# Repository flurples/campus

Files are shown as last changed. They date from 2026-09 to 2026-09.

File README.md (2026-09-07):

# campus
mechanical keyboard conversion for a framework 13

IMG_3377-adjusted
build video: https://youtu.be/kGHAUogFsYY

## about
campus is designed to be a drop-in replacement housing for a framework 13 that features a hhkb layout kailh choc mechanical keyboard.

## you will need
- a framework 13 laptop
#### bottom chassis parts
- bottom chassis (cnc)
- bottom-bracket-R, L & M (3d print)
#### input cover parts
- input cover (cnc)
- plate (cnc)
- 3x knobs (cnc)
- 1x touchpad-clamp-R & L (3d print)
- 2x touchpad-clamp-top (3d print)
#### lid parts
- lid (cnc)
- bezel (3d print)
- lid-corner-cap-R & L (3d print)
#### other hardware
- 60x kailh choc switches
- choc stabilizers (2x 2u, 1x 6.25u)
- compatible keycaps (be sure to get 6.25u space, 1.75u shift, etc)
- 3x ec12 low profile encoders
- m1.6 x 3mm heat set inserts
- m2 x 4mm heat set inserts
- m2 x 2.5mm heat set inserts
- 5x m2 x 20mm flat head hex screws (to screw the chassis together)
- 3x m2 x 8mm set screws (for the knobs)
- 4x 1" OD rubber bumpers
- variety of double sided tapes
- epoxy

## build notes
bottom chassis, input cover, lid, knobs, and plate were cnc'd from aluminum. all 3d printed parts were printed in petg to avoid breaking down over the years. heat set inserts for screw holes to mount factory components are installed into the bottom-brackets, which are then epoxied to the bottom-chassis. due to jlcpcb's minimum thickness requirements, the input and lid do not use heat set inserts. instead, the aluminum is directly tapped.

#### the keyboard workaround
the usb hub was too complex and I wasn't able to get it working. because the keyboard was originally meant to connect internally through the usb hub, I ended up simply bypassing the usb hub entirely, bypassing it with a unified daughterboard s1.
in case anyone wants to attempt to diagnose why, I've uploaded the kicad files as is for reference.

## disclaimer
campus is a highly involved project and will require completely tearing down your framework laptop and transplanting all the components into an objectively worse-designed chassis than the factory framework chassis. some features will be lost, for example, the privacy switches built into the webcam module, or the little buttons that lock the expansion cards in place. I am not a professional electronics designer, so expect to perform some janky workarounds to get the laptop functioning as it should. I am not responsible for any issues you may encounter with the build, so please use the files with caution.

I do not sell any products, and I am not affiliated with any vendors who claim to sell my designs. if you choose to support these vendors, I am not responsible for any issues you may encounter with them.

## gallery






IMG_E3424

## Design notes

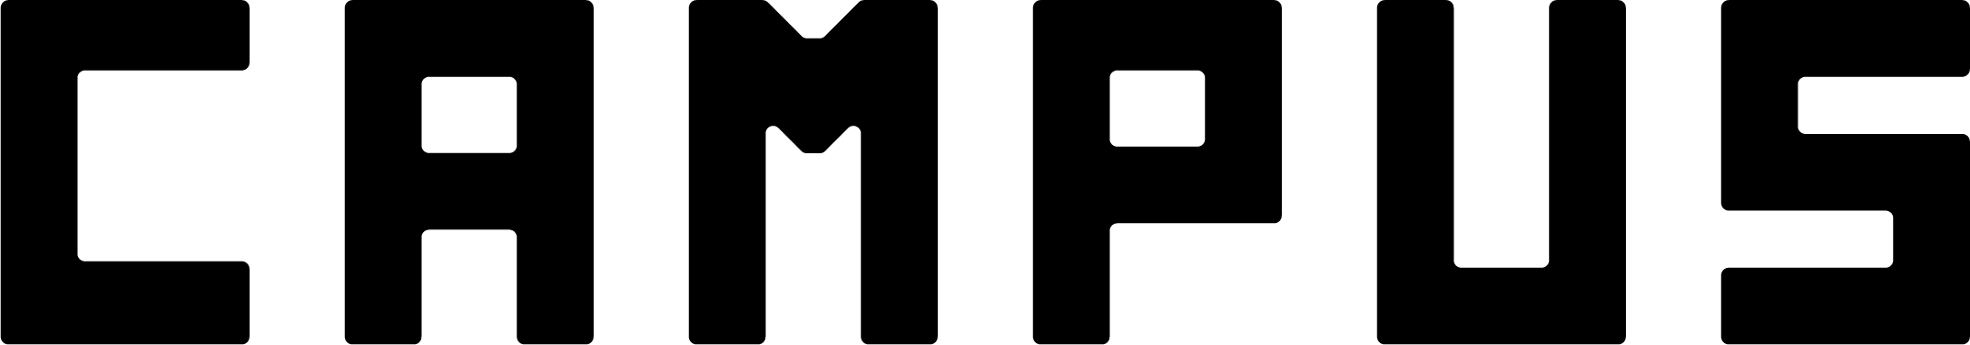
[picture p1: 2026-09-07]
graphics/campus-text.png

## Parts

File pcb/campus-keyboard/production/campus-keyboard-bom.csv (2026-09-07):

Comment | Designator | Footprint | LCSC Part Number
22pF | C1,C2 | Capacitor_SMD:C_0805_2012Metric | C1804
1uF | C3 | Capacitor_SMD:C_0805_2012Metric | C28323
0.1uF | C4,C5,C6 | Capacitor_SMD:C_0805_2012Metric | C1711
10uF | C7 | Capacitor_SMD:C_0805_2012Metric | C1713
SOD-123 | D1,D2,D3,D4,D5,D6,D7,D8,D9,D10,D11,D12,D13,D14,D15,D16,D17,D18,D19,D20,D21,D22,D23,D24,D25,D26,D27,D28,D29,D30,D31,D32,D33,D34,D35,D36,D37,D38,D39,D40,D41,D42,D43,D44,D45,D46,D47,D48,D49,D50,D51,D52,D53,D54,D55,D56,D57,D58,D59,D60 | Diode_SMD:D_SOD-123 | C2099
500mA | F1 | Fuse:Fuse_1206_3216Metric | C720075
Conn_01x04 | J1 | Connector_Molex:Molex_Pico-EZmate_78171-0004_1x04-1MP_P1.20mm_Vertical | C588524
SI2302 | Q1 | Package_TO_SOT_SMD:SOT-23 | C2891732
470 | R1,R2,R3,R4,R5,R6,R7,R8,R9,R10,R11,R12,R13,R14,R15,R16,R17,R18,R19,R20,R21,R22,R23,R24,R25,R26,R27,R28,R29,R30,R31,R32,R33,R34,R35,R36,R37,R38,R39,R40,R41,R42,R43,R44,R45,R46,R47,R48,R49,R50,R51,R52,R53,R54,R55,R56,R57,R58,R59,R60,R61,R62,R63,R64,R65,R66,R67,R68,R69,R70,R71,R72,R73,R74,R75,R76,R77,R78,R79,R80,R81 | campus-parts:R_0805_2012Metric | C17710
10k | R82,R83,R86 | campus-parts:R_0805_2012Metric | C17414
22 | R84,R85 | campus-parts:R_0805_2012Metric | C17561
SW_Push | SW1 | random-keyboard-parts:SKQG-1155865 | C5140332
ATmega32U4-MU | U1 | Package_DFN_QFN:QFN-44-1EP_7x7mm_P0.5mm_EP5.2x5.2mm | C112161
16MHz | Y1 | Crystal:Crystal_SMD_3225-4Pin_3.2x2.5mm | C13738

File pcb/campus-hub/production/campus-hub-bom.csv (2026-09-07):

Comment | Designator | Footprint | LCSC Part Number
10uF | C9 | Capacitor_SMD:C_0805_2012Metric | C1713
1uF | C13 | Capacitor_SMD:C_0805_2012Metric | C28323
22uF | C14 | Capacitor_SMD:C_0805_2012Metric | C5674
4.7uF | C18,C30 | Capacitor_SMD:C_0805_2012Metric | C1779
22pF | C23,C24,C33,C34 | Capacitor_SMD:C_0805_2012Metric | C1804
0.33uF | C5,C6 | Capacitor_SMD:C_0805_2012Metric | C73142
0.1uF | C7,C8,C10,C11,C12,C15,C16,C17,C19,C20,C21,C22,C25,C26,C27,C28,C29,C31,C32,C35,C36,C37,C38 | Capacitor_SMD:C_0805_2012Metric | C1711
1uH | L1 | Inductor_SMD:L_1008_2520Metric | C5179444
5.1k | R1 | Resistor_SMD:R_0805_2012Metric | C27834
24.9k | R2 | Resistor_SMD:R_0805_2012Metric | C17571
113k | R3 | Resistor_SMD:R_0805_2012Metric | C17424
1M | R5 | Resistor_SMD:R_0805_2012Metric | C2889485
33 | R11 | Resistor_SMD:R_0805_2012Metric | C17634
12k | R4,R12 | Resistor_SMD:R_0805_2012Metric | C17444
10k | R6,R7,R8,R9,R10,R14,R15 | Resistor_SMD:R_0805_2012Metric | C17414
TUSB1046-DCIRNQR | U1 | campus-parts:RNQ40_TEX | C2151061
USB5744/2G | U2 | campus-parts:VQFN56_2G_MCH | C633621
TPS62901RPJR | U3 | campus-parts:QFN_902RPJR_TEX | C2864847
USB2244-AEZG-06 | U4 | campus-parts:QFN36_6X6MC_MCH | C2674043
25MHz | Y1 | Crystal:Crystal_SMD_3225-4Pin_3.2x2.5mm | C9006
24MHz | Y2 | Crystal:Crystal_SMD_3225-4Pin_3.2x2.5mm | C7294566

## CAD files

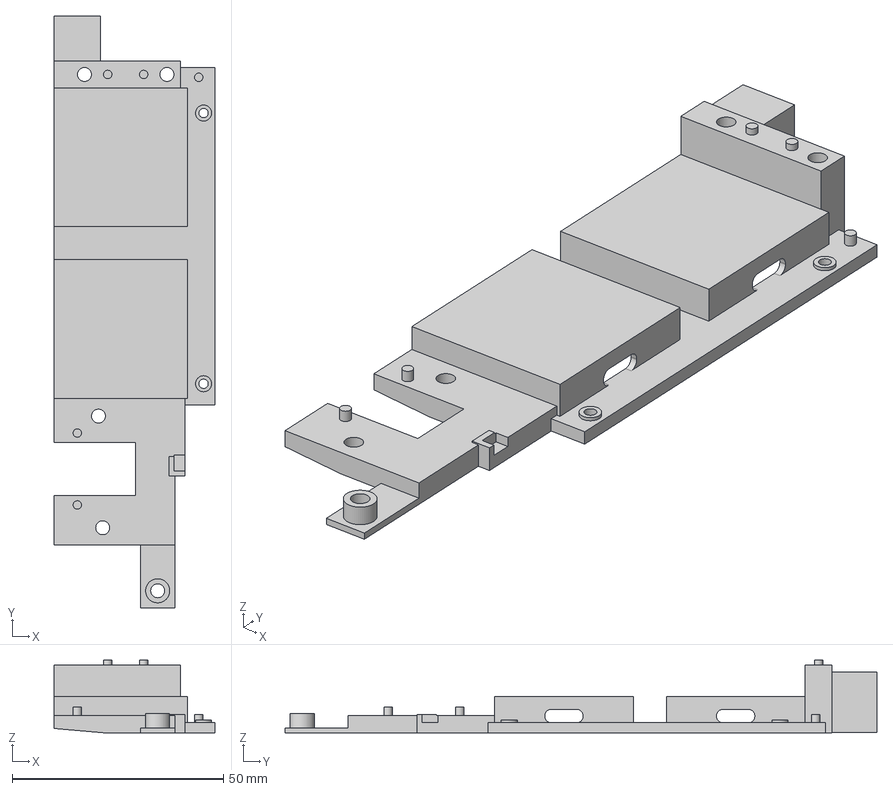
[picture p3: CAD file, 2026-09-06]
components/3dprint/bottom/bottom-bracket-L.step
38.1 x 139.9 x 17.2 mm

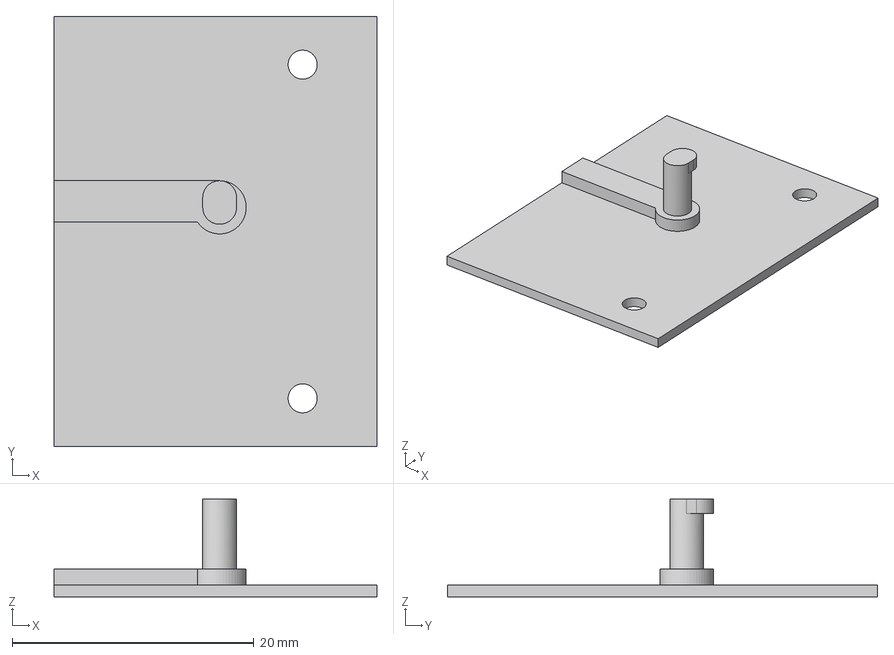
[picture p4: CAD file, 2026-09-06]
components/3dprint/input-cover/touchpad-clamp-R.step
26.7 x 35.6 x 8.10 mm
fingerprint-bracket
touchpad-bracket
encoder-bracket
edge-bracket
touchpad-clamps
corner-bracket

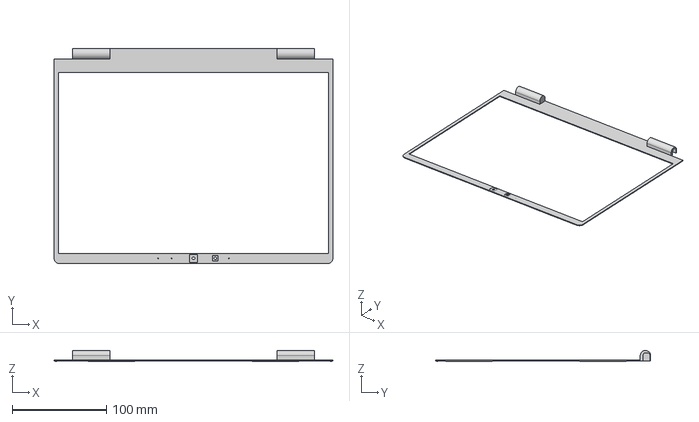
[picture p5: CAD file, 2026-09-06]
components/3dprint/lid/bezel.step
296.6 x 229.0 x 11.8 mm

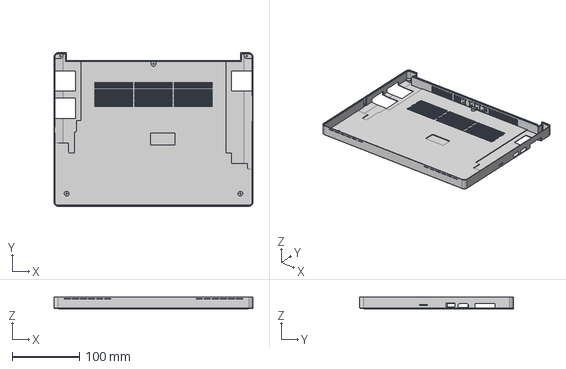
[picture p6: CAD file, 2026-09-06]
components/cnc/bottom/chassis-bottom.step
296.6 x 229.0 x 18.4 mm

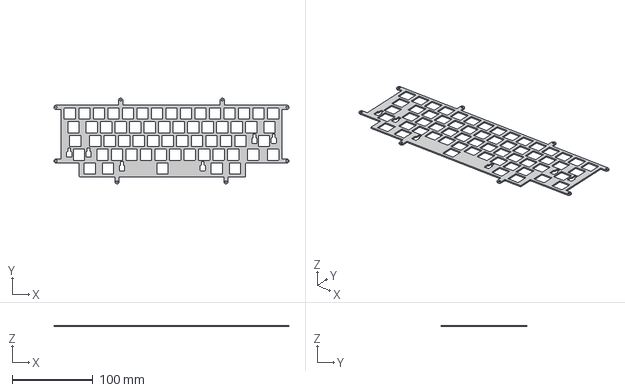
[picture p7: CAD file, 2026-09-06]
components/cnc/input-cover/plate.step
291.4 x 106.4 x 1.50 mm

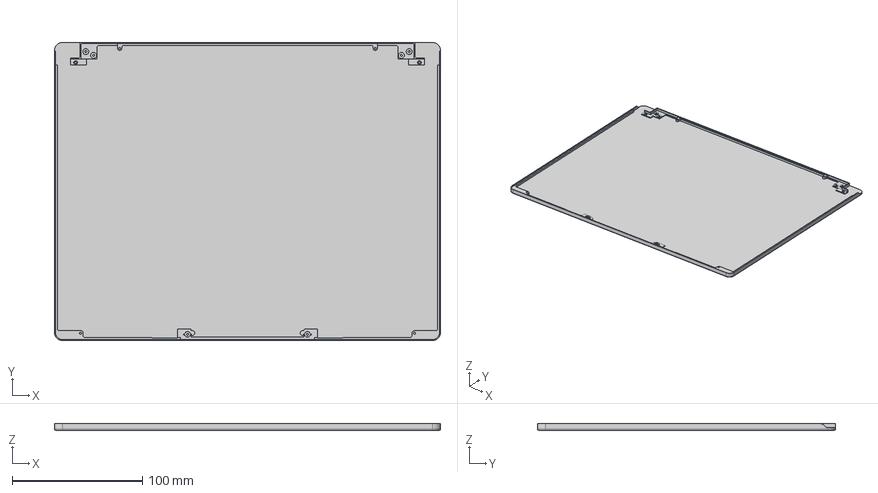
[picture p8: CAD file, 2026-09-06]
components/cnc/lid/lid.step
296.6 x 229.0 x 5.00 mm

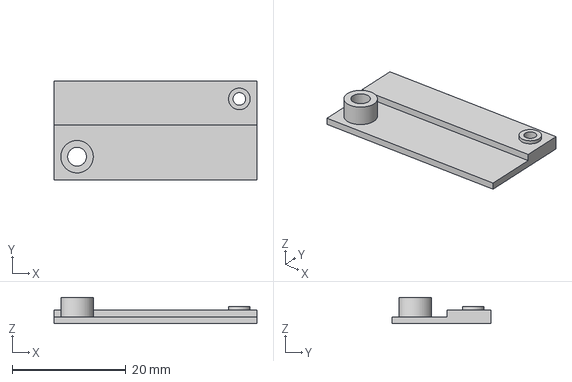
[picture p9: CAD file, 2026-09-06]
components/3dprint/bottom/bottom-bracket-M.step
35.6 x 17.3 x 4.60 mm

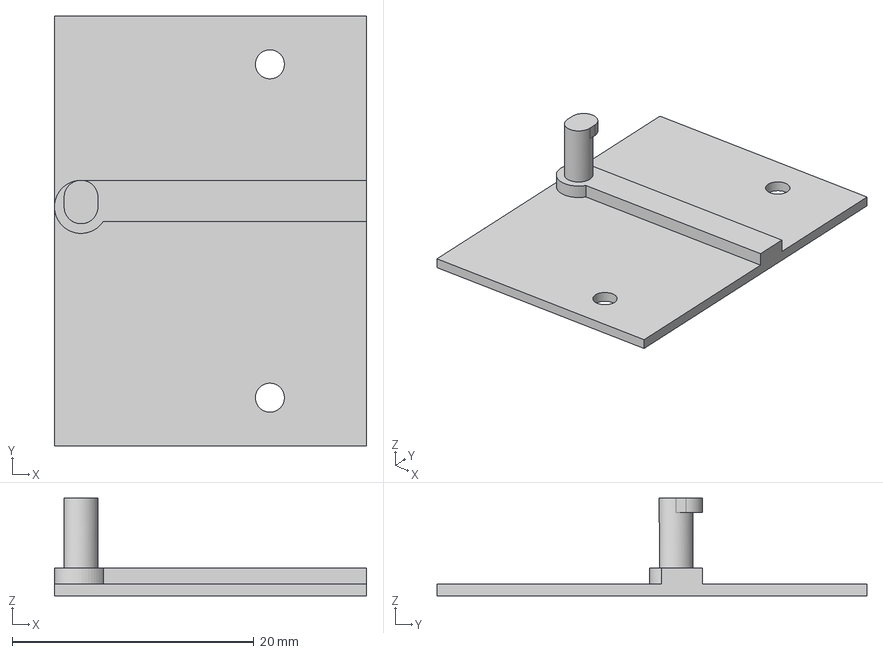
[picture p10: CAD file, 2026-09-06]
components/3dprint/input-cover/touchpad-clamp-L.step
25.8 x 35.6 x 8.10 mm
fingerprint-bracket
touchpad-bracket
encoder-bracket
edge-bracket
touchpad-clamps
corner-bracket

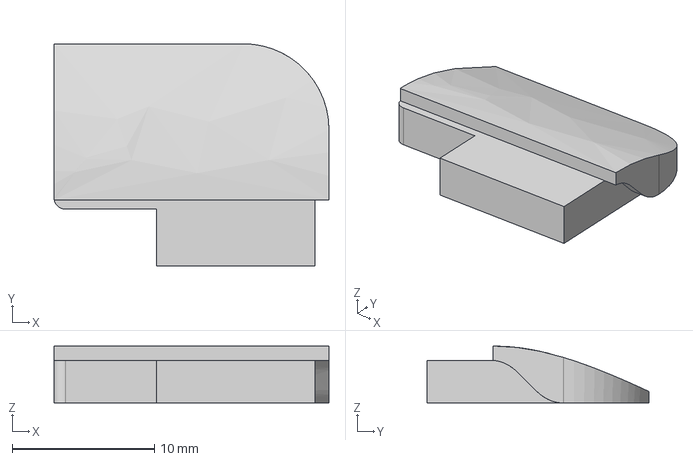
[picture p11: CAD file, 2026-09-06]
components/3dprint/lid/lid-corner-cap-L.step
19.3 x 15.6 x 4.00 mm

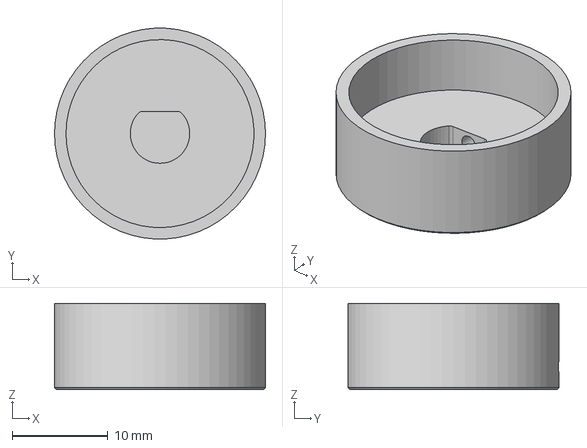
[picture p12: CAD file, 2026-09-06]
components/cnc/input-cover/knob.step
22.0 x 22.0 x 9.00 mm

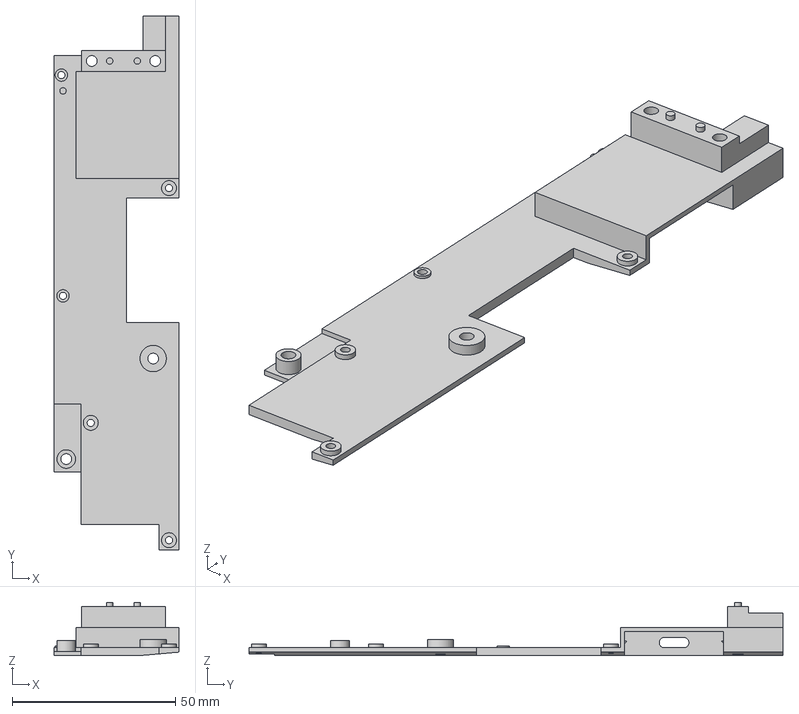
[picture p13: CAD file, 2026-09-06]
components/3dprint/bottom/bottom-bracket-R.step
38.2 x 163.8 x 16.3 mm

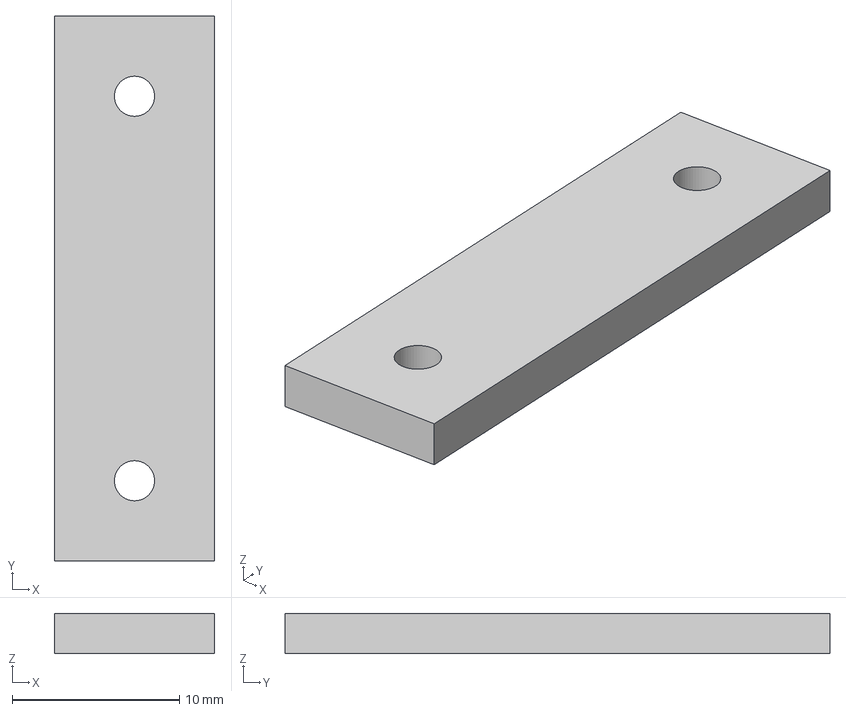
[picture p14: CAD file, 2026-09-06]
components/3dprint/input-cover/touchpad-clamp-top.step
9.60 x 32.6 x 2.40 mm
fingerprint-bracket
touchpad-bracket
encoder-bracket
edge-bracket
touchpad-clamps
corner-bracket

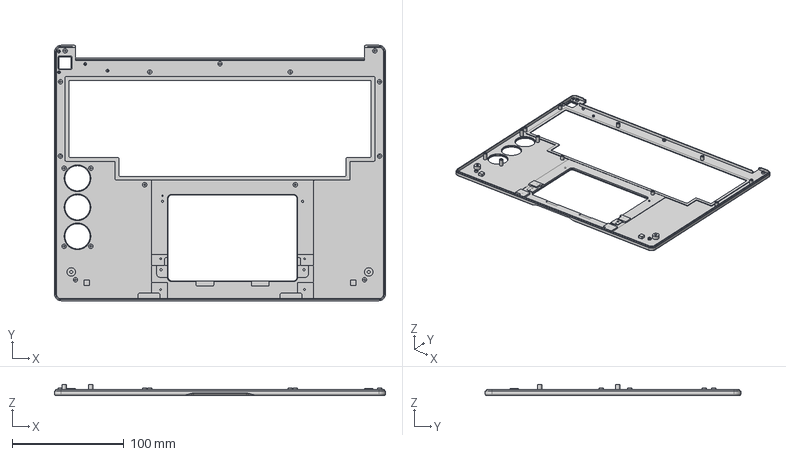
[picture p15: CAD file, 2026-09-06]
components/cnc/input-cover/chassis-input-cover.step
296.6 x 229.0 x 9.70 mm

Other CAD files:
components/3dprint/lid/lid-corner-cap-R.step

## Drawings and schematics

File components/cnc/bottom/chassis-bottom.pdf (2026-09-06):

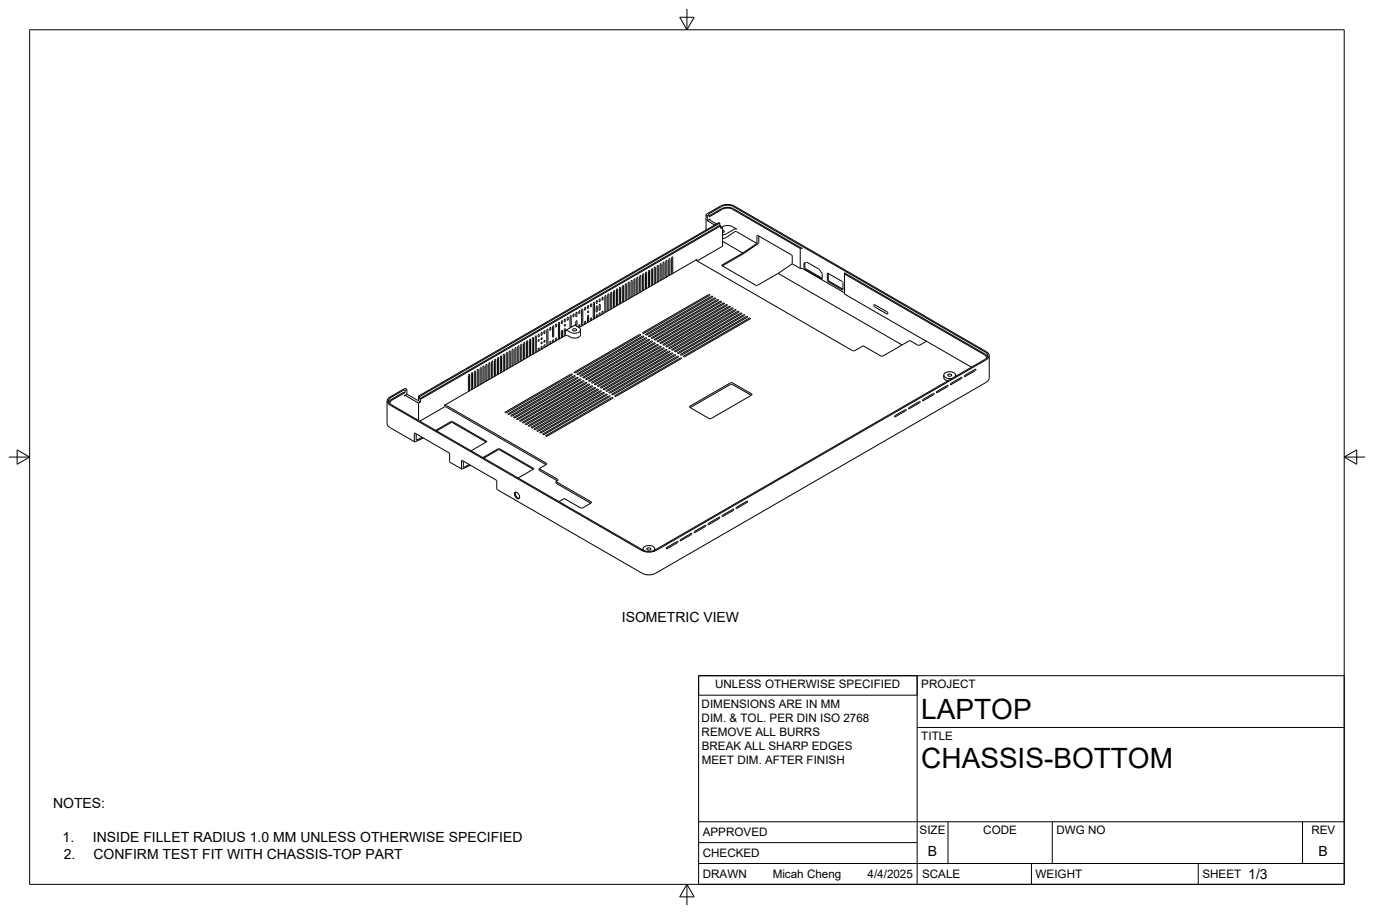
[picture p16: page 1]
SIZE; CODE; DWG NO; REV; Micah Cheng; ISOMETRIC VIEW

UNLESS OTHERWISE SPECIFIED
DIMENSIONS ARE IN MM
DIM. & TOL. PER DIN ISO 2768
REMOVE ALL BURRS
BREAK ALL SHARP EDGES
MEET DIM. AFTER FINISH

1. INSIDE FILLET RADIUS 1.0 MM UNLESS OTHERWISE SPECIFIED
2. CONFIRM TEST FIT WITH CHASSIS-TOP PART

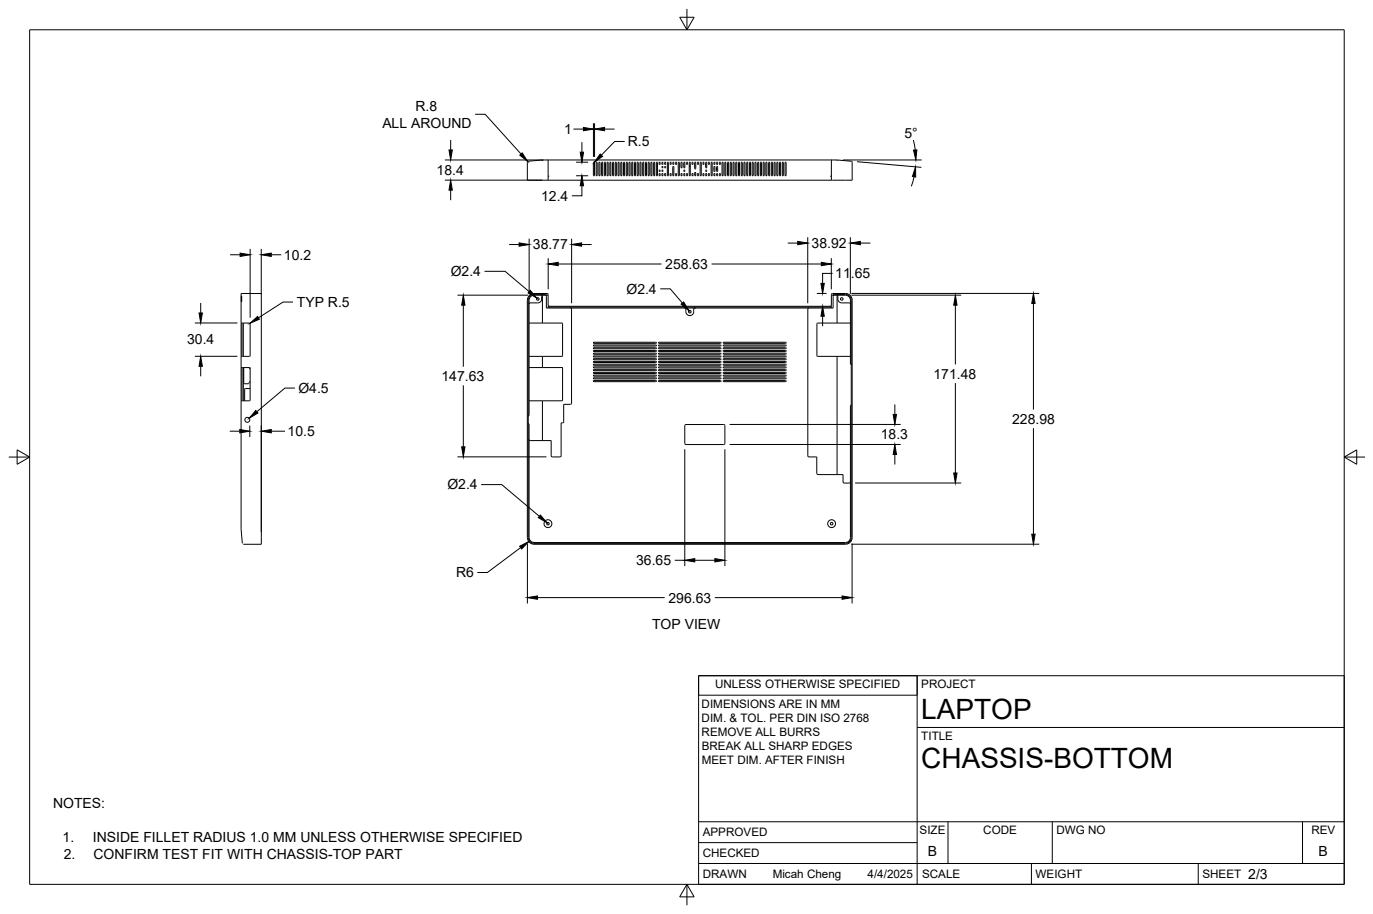
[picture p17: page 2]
SIZE; CODE; DWG NO; REV; TYP R.5; ALL AROUND; TOP VIEW

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

1. INSIDE FILLET RADIUS 1.0 MM UNLESS OTHERWISE SPECIFIED

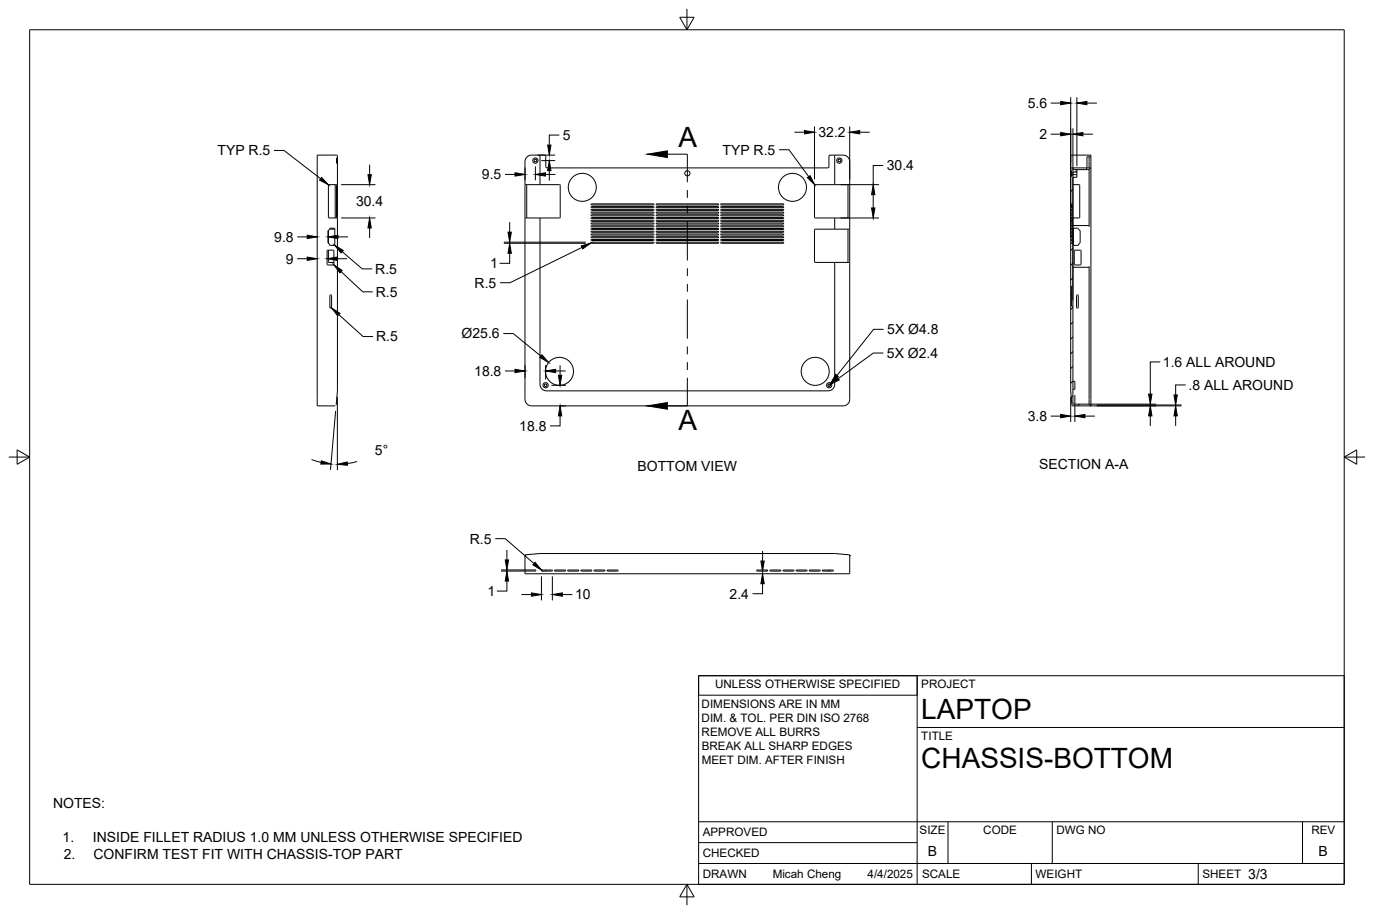
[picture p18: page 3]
SIZE; CODE; DWG NO; REV; BOTTOM VIEW; SECTION A-A; TYP R.5; .8 ALL AROUND; 1.6 ALL AROUND

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

1. INSIDE FILLET RADIUS 1.0 MM UNLESS OTHERWISE SPECIFIED

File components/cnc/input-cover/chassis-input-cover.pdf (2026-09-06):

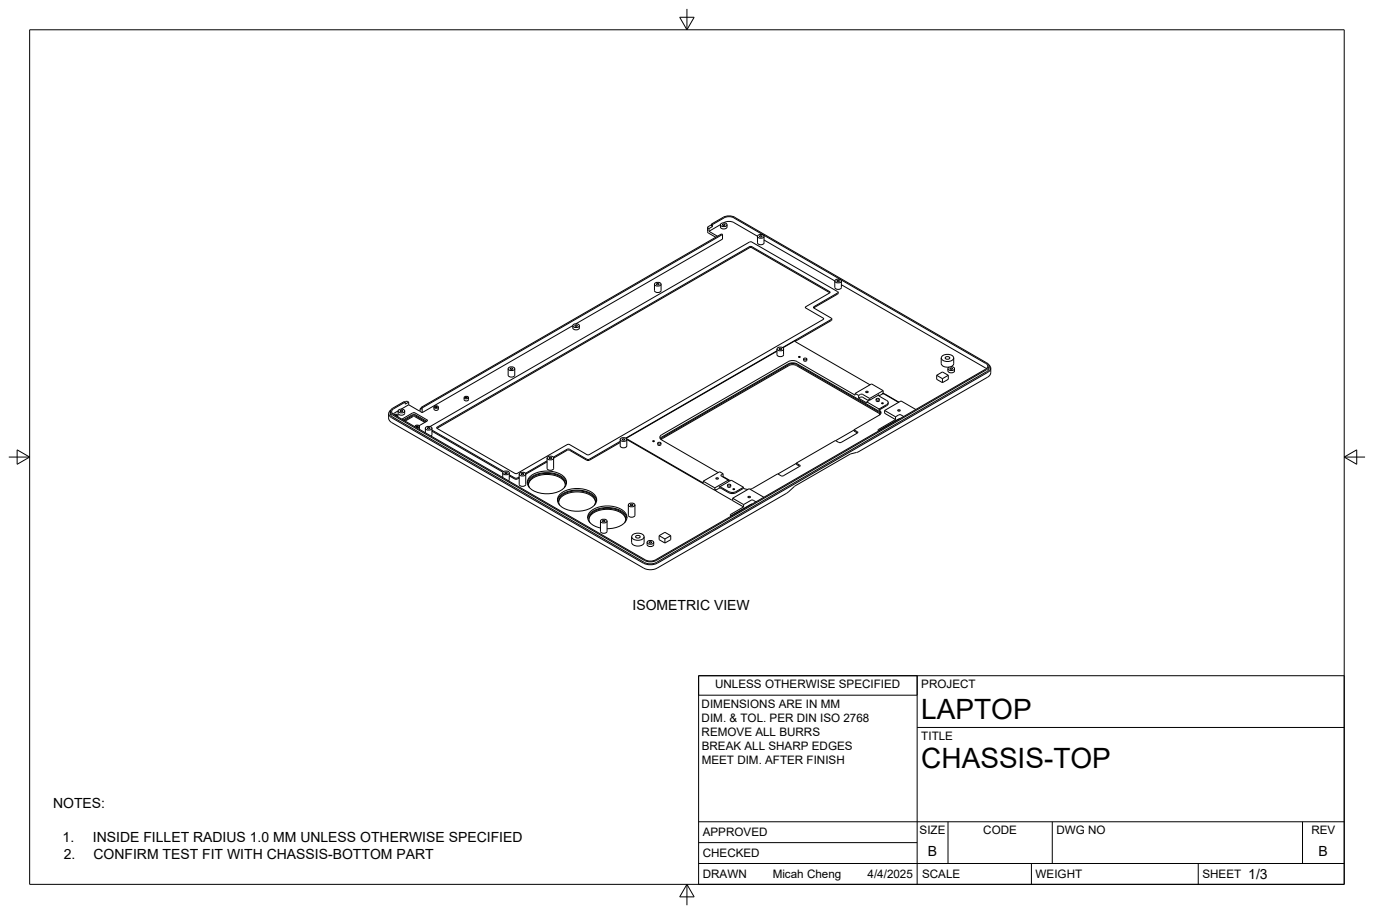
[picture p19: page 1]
SIZE; CODE; DWG NO; REV; Micah Cheng; ISOMETRIC VIEW

UNLESS OTHERWISE SPECIFIED
DIMENSIONS ARE IN MM
DIM. & TOL. PER DIN ISO 2768
REMOVE ALL BURRS
BREAK ALL SHARP EDGES
MEET DIM. AFTER FINISH

1. INSIDE FILLET RADIUS 1.0 MM UNLESS OTHERWISE SPECIFIED
2. CONFIRM TEST FIT WITH CHASSIS-BOTTOM PART

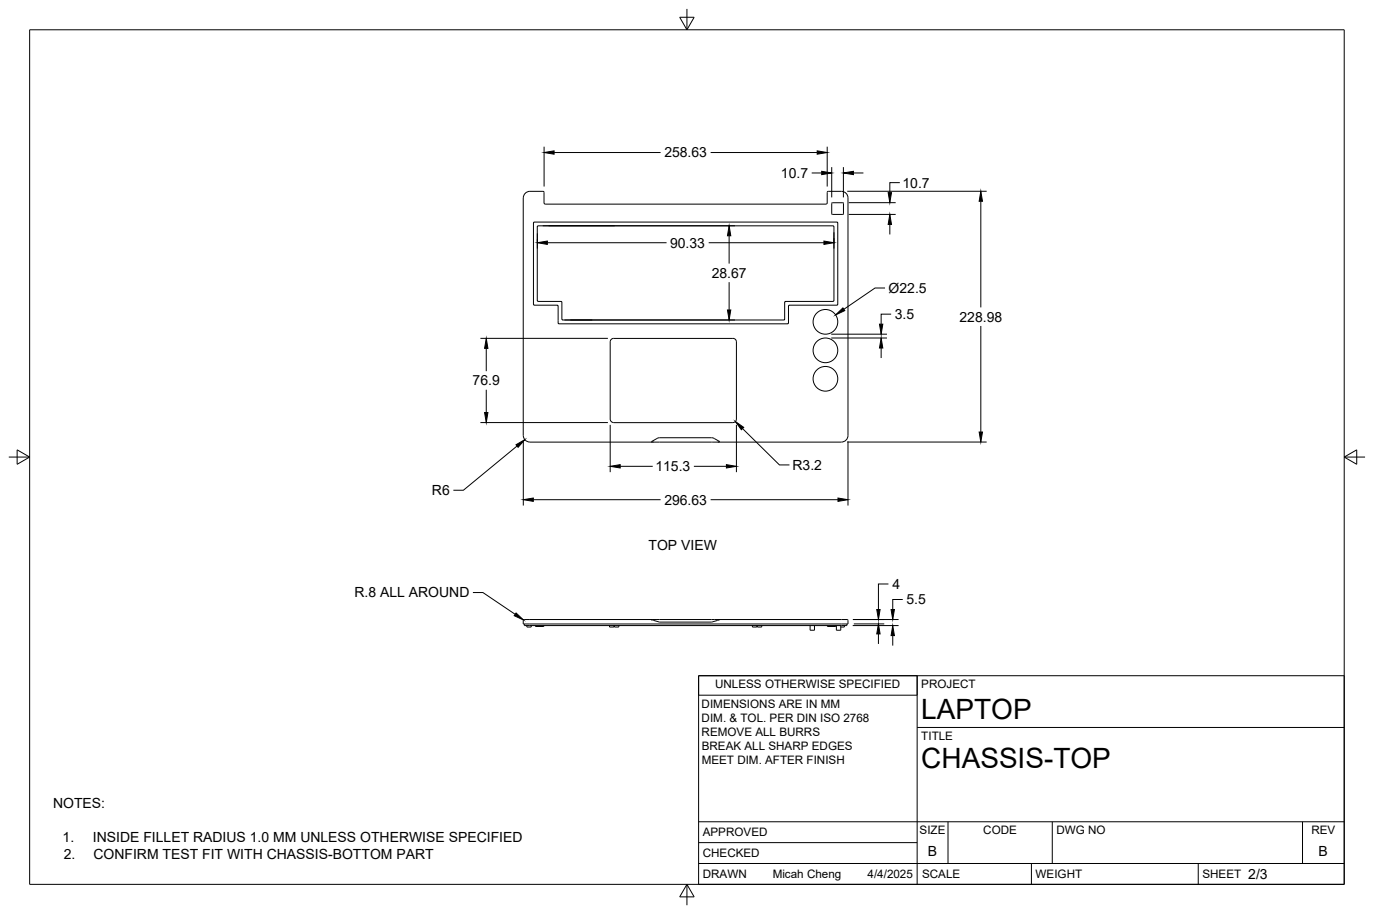
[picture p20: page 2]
SIZE; CODE; DWG NO; REV; TOP VIEW; 4 R.8 ALL AROUND

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

1. INSIDE FILLET RADIUS 1.0 MM UNLESS OTHERWISE SPECIFIED

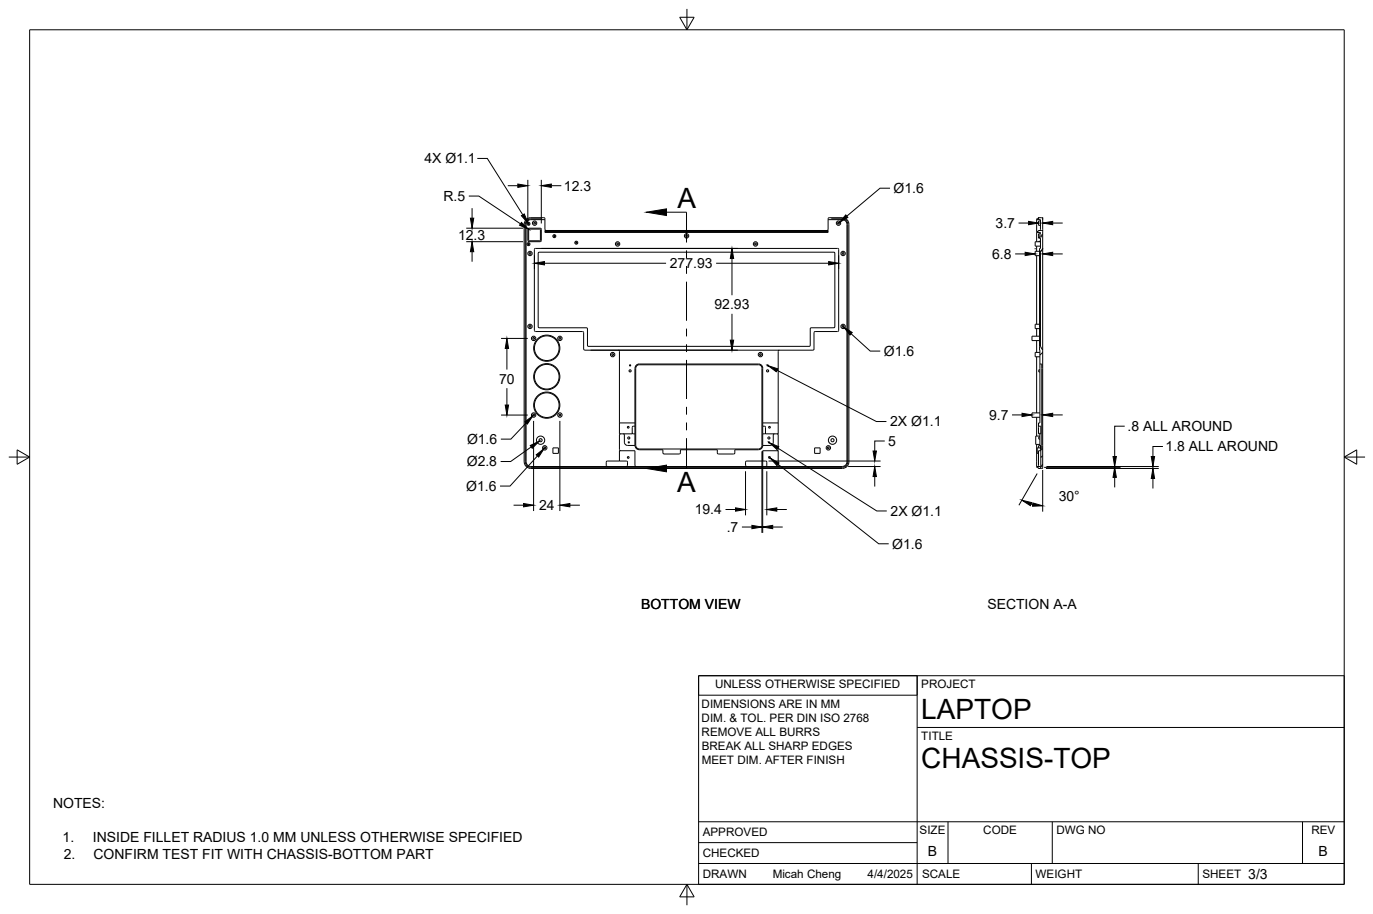
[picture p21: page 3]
SIZE; CODE; DWG NO; REV; BOTTOM VIEW; SECTION A-A; 1.8 ALL AROUND; .8 ALL AROUND

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

1. INSIDE FILLET RADIUS 1.0 MM UNLESS OTHERWISE SPECIFIED

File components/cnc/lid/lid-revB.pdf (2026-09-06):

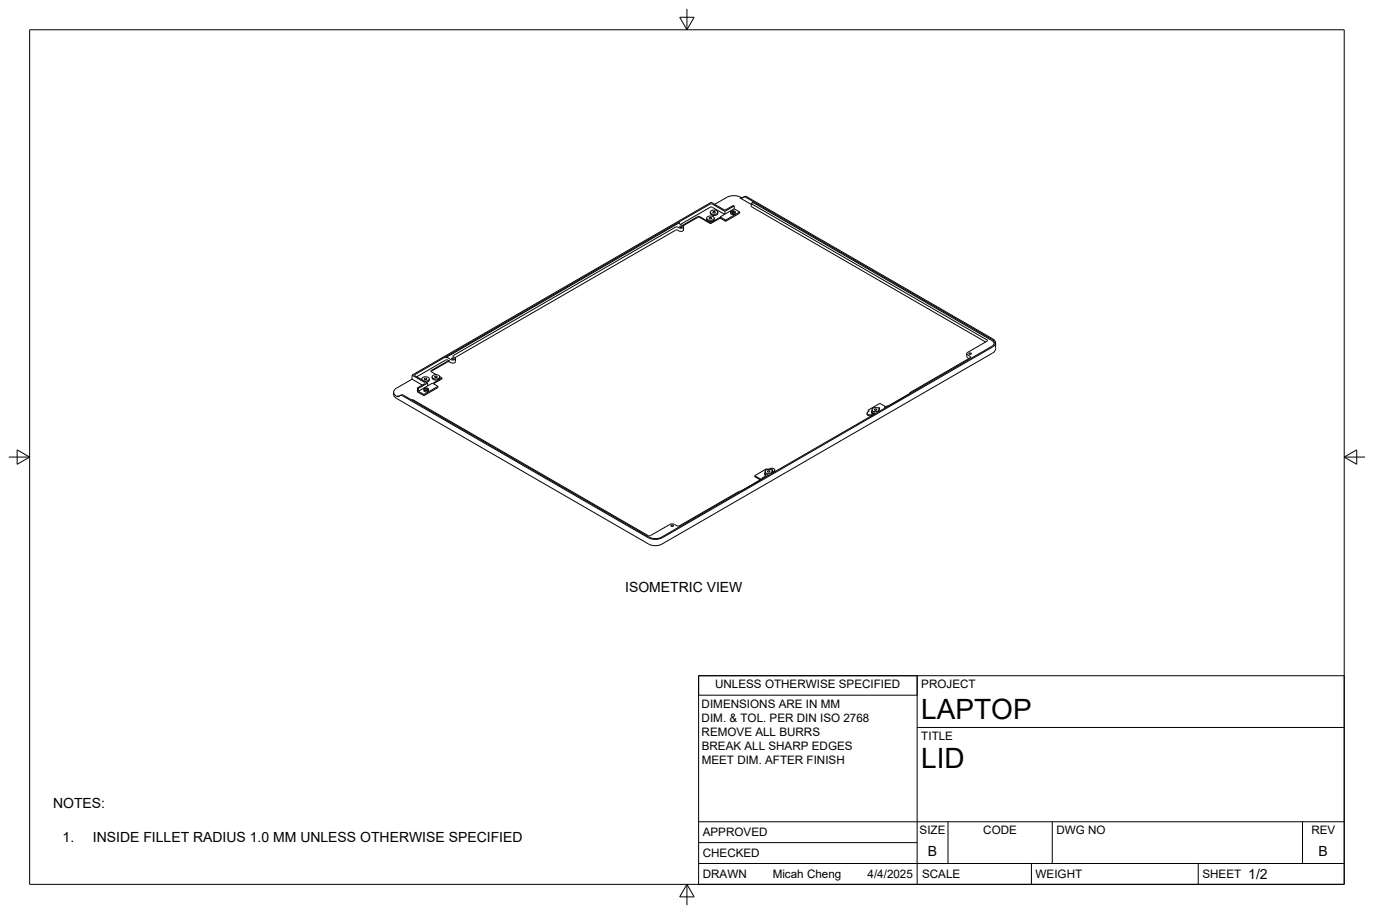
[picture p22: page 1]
SIZE; CODE; DWG NO; REV; Micah Cheng; ISOMETRIC VIEW

UNLESS OTHERWISE SPECIFIED
DIMENSIONS ARE IN MM
DIM. & TOL. PER DIN ISO 2768
REMOVE ALL BURRS
BREAK ALL SHARP EDGES
MEET DIM. AFTER FINISH

1. INSIDE FILLET RADIUS 1.0 MM UNLESS OTHERWISE SPECIFIED

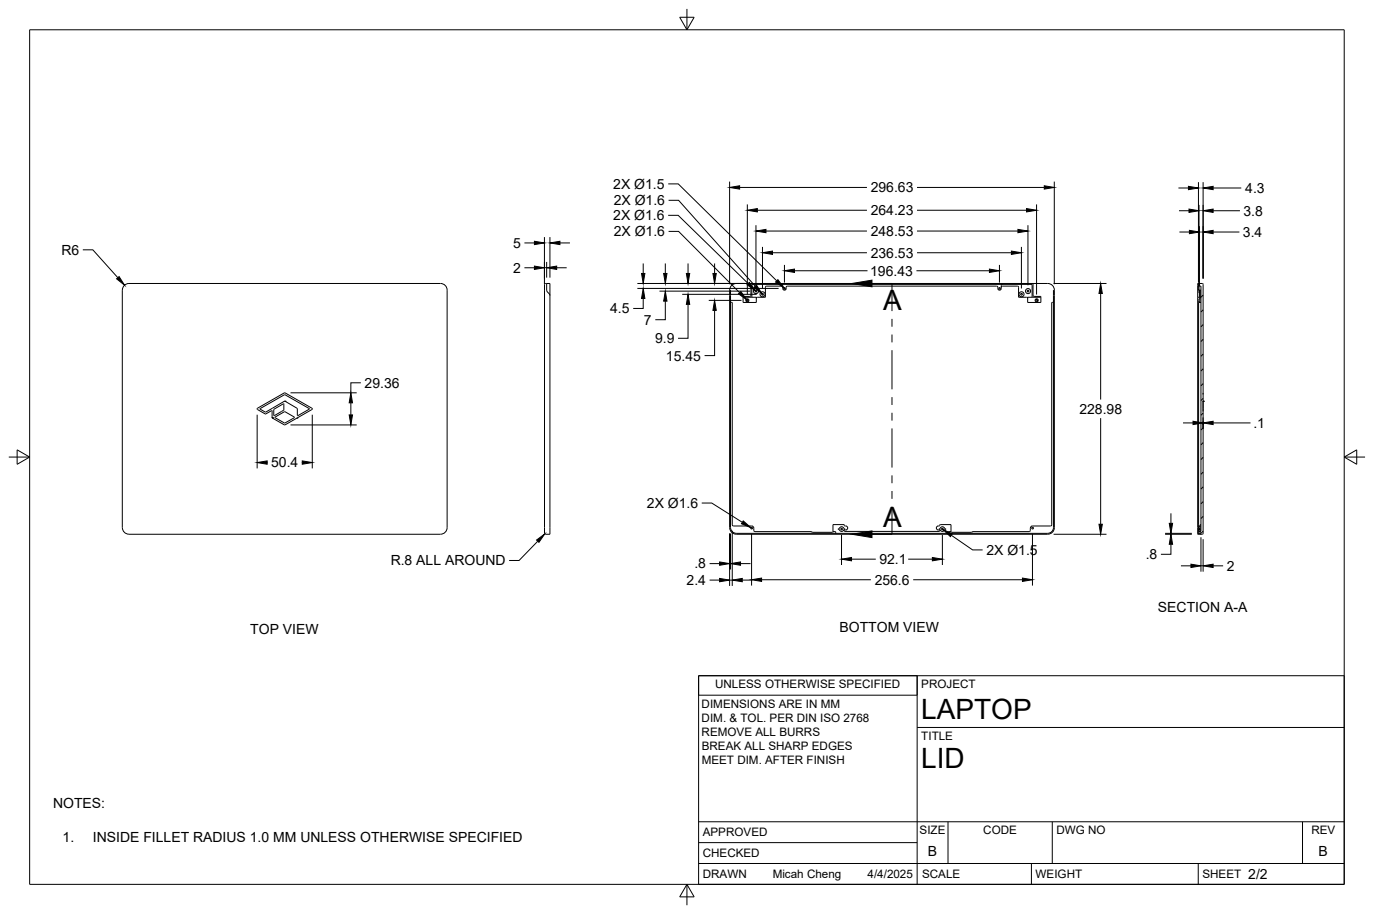
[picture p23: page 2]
SIZE; CODE; DWG NO; REV; Micah Cheng; SECTION A-A; R.8 ALL AROUND; TOP VIEW; BOTTOM VIEW

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

1. INSIDE FILLET RADIUS 1.0 MM UNLESS OTHERWISE SPECIFIED

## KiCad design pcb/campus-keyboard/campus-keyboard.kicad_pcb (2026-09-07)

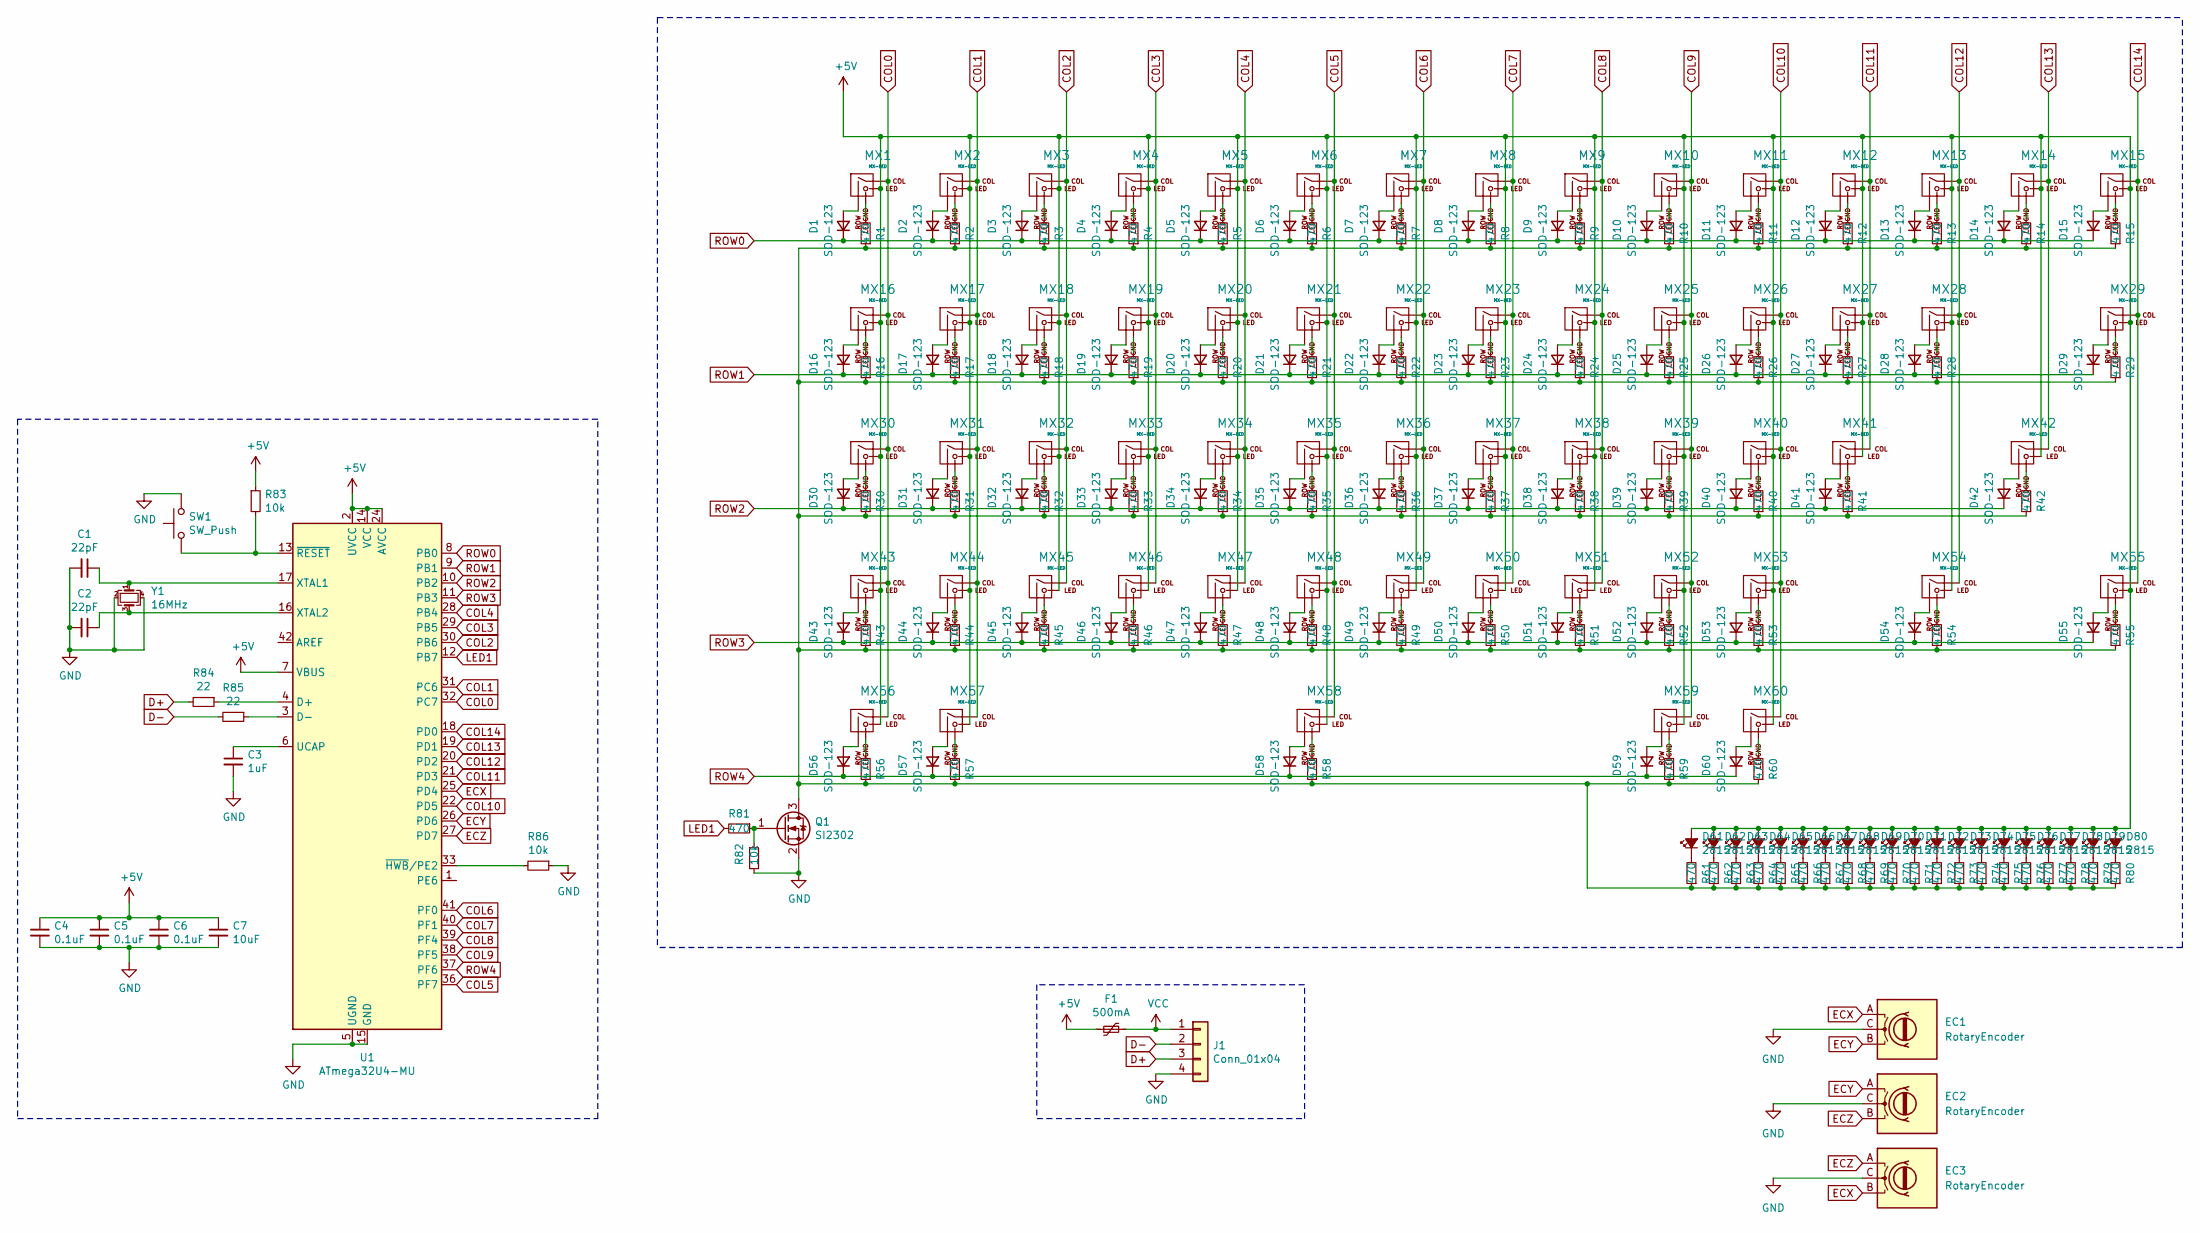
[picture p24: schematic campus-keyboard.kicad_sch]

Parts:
C1, C2: 22pF; C_0805_2012Metric
C3: 1uF; C_0805_2012Metric
C4, C5, C6: 0.1uF; C_0805_2012Metric
C7: 10uF; C_0805_2012Metric
D1, D2, D3, D4, D5, D6, D7, D8, D9, D10, D11, D12, D13, D14, D15, D16, D17, D18, D19, D20, D21, D22, D23, D24, D25, D26, D27, D28, D29, D30, D31, D32, D33, D34, D35, D36, D37, D38, D39, D40, D41, D42, D43, D44, D45, D46, D47, D48, D49, D50, D51, D52, D53, D54, D55, D56, D57, D58, D59, D60: SOD-123; D_SOD-123-CenterREF__
D61, D62, D63, D64, D65, D66, D67, D68, D69, D70, D71, D72, D73, D74, D75, D76, D77, D78, D79, D80: 2815; GW JCLPS2.EM
EC1, EC2, EC3: RotaryEncoder; SW3_EC12E1220301_ALPS
F1: 500mA; Fuse_1206_3216Metric
J1: Conn_01x04; Molex_Pico-EZmate_78171-0004_1x04-1MP_P1.20mm_Vertical
MX1, MX2, MX3, MX4, MX5, MX6, MX7, MX8, MX9, MX10, MX11, MX12, MX13, MX14, MX15, MX17, MX18, MX19, MX20, MX21, MX22, MX23, MX24, MX25, MX26, MX27, MX28, MX31, MX32, MX33, MX34, MX35, MX36, MX37, MX38, MX39, MX40, MX41, MX44, MX45, MX46, MX47, MX48, MX49, MX50, MX51, MX52, MX53, MX55: MX-LED; Choc-1u-GW
MX16, MX29: MX-LED; Choc-1.5u-GW
MX30, MX54: MX-LED; Choc-1.75u-GW
MX42, MX43: MX-LED; Choc-2.25u-GW
MX56, MX57, MX59, MX60: MX-LED; Choc-1.25u-GW
MX58: MX-LED; Choc-6.25u-GW
Q1: SI2302; SOT-23
R1, R2, R3, R4, R5, R6, R7, R8, R9, R10, R11, R12, R13, R14, R15, R16, R17, R18, R19, R20, R21, R22, R23, R24, R25, R26, R27, R28, R29, R30, R31, R32, R33, R34, R35, R36, R37, R38, R39, R40, R41, R42, R43, R44, R45, R46, R47, R48, R49, R50, R51, R52, R53, R54, R55, R56, R57, R58, R59, R60, R61, R62, R63, R64, R65, R66, R67, R68, R69, R70, R71, R72, R73, R74, R75, R76, R77, R78, R79, R80, R81: 470; R_0805_2012Metric-CenterREF__
R82, R83, R86: 10k; R_0805_2012Metric-CenterREF__
R84, R85: 22; R_0805_2012Metric-CenterREF__
SW1: SW_Push; SKQG-1155865
U1: ATmega32U4-MU; QFN-44-1EP_7x7mm_P0.5mm_EP5.2x5.2mm
Y1: 16MHz; Crystal_SMD_3225-4Pin_3.2x2.5mm

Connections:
+5V: C4.1, C5.1, C6.1, C7.1, D61.2 (A), D62.2 (A), D63.2 (A), D64.2 (A), D65.2 (A), D66.2 (A), D67.2 (A), D68.2 (A), D69.2 (A), D70.2 (A), D71.2 (A), D72.2 (A), D73.2 (A), D74.2 (A), D75.2 (A), D76.2 (A), D77.2 (A), D78.2 (A), D79.2 (A), D80.2 (A), F1.2, MX1.3 (LED), MX2.3 (LED), MX3.3 (LED), MX4.3 (LED), MX5.3 (LED), MX6.3 (LED), MX7.3 (LED), MX8.3 (LED), MX9.3 (LED), MX10.3 (LED), MX11.3 (LED), MX12.3 (LED), MX13.3 (LED), MX14.3 (LED), MX15.3 (LED), MX16.3 (LED), MX17.3 (LED), MX18.3 (LED), MX19.3 (LED), MX20.3 (LED), MX21.3 (LED), MX22.3 (LED), MX23.3 (LED), MX24.3 (LED), MX25.3 (LED), MX26.3 (LED), MX27.3 (LED), MX28.3 (LED), MX29.3 (LED), MX30.3 (LED), MX31.3 (LED), MX32.3 (LED), MX33.3 (LED), MX34.3 (LED), MX35.3 (LED), MX36.3 (LED), MX37.3 (LED), MX38.3 (LED), MX39.3 (LED), MX40.3 (LED), MX41.3 (LED), MX42.3 (LED), MX43.3 (LED), MX44.3 (LED), MX45.3 (LED), MX46.3 (LED), MX47.3 (LED), MX48.3 (LED), MX49.3 (LED), MX50.3 (LED), MX51.3 (LED), MX52.3 (LED), MX53.3 (LED), MX54.3 (LED), MX55.3 (LED), MX56.3 (LED), MX57.3 (LED), MX58.3 (LED), MX59.3 (LED), MX60.3 (LED), R83.1, U1.2 (UVCC), U1.7 (VBUS), U1.14 (VCC), U1.24 (AVCC), U1.34 (VCC), U1.44 (AVCC)
COL0: MX1.1 (COL), MX16.1 (COL), MX30.1 (COL), MX43.1 (COL), MX56.1 (COL), U1.32 (PC7)
COL1: MX2.1 (COL), MX17.1 (COL), MX31.1 (COL), MX44.1 (COL), MX57.1 (COL), U1.31 (PC6)
COL2: MX3.1 (COL), MX18.1 (COL), MX32.1 (COL), MX45.1 (COL), U1.30 (PB6)
COL3: MX4.1 (COL), MX19.1 (COL), MX33.1 (COL), MX46.1 (COL), U1.29 (PB5)
COL4: MX5.1 (COL), MX20.1 (COL), MX34.1 (COL), MX47.1 (COL), U1.28 (PB4)
COL5: MX6.1 (COL), MX21.1 (COL), MX35.1 (COL), MX48.1 (COL), MX58.1 (COL), U1.36 (PF7)
COL6: MX7.1 (COL), MX22.1 (COL), MX36.1 (COL), MX49.1 (COL), U1.41 (PF0)
COL7: MX8.1 (COL), MX23.1 (COL), MX37.1 (COL), MX50.1 (COL), U1.40 (PF1)
COL8: MX9.1 (COL), MX24.1 (COL), MX38.1 (COL), MX51.1 (COL), U1.39 (PF4)
COL9: MX10.1 (COL), MX25.1 (COL), MX39.1 (COL), MX52.1 (COL), MX59.1 (COL), U1.38 (PF5)
COL10: MX11.1 (COL), MX26.1 (COL), MX40.1 (COL), MX53.1 (COL), MX60.1 (COL), U1.22 (PD5)
COL11: MX12.1 (COL), MX27.1 (COL), MX41.1 (COL), U1.21 (PD3)
COL12: MX13.1 (COL), MX28.1 (COL), MX54.1 (COL), U1.20 (PD2)
COL13: MX14.1 (COL), MX42.1 (COL), U1.19 (PD1)
COL14: MX15.1 (COL), MX29.1 (COL), MX55.1 (COL), U1.18 (PD0)
D+: J1.3, R84.2
D-: J1.2, R85.2
ECX: EC1.1, EC1.A, EC3.3, EC3.B, U1.25 (PD4)
ECY: EC1.3, EC1.B, EC2.1, EC2.A, U1.26 (PD6)
ECZ: EC2.3, EC2.B, EC3.1, EC3.A, U1.27 (PD7)
GND: C1.2, C2.2, C3.2, C4.2, C5.2, C6.2, C7.2, EC1.2, EC1.C, EC2.2, EC2.C, EC3.2, EC3.C, J1.4, Q1.2 (S), R82.2, R86.1, SW1.2, U1.5 (UGND), U1.15 (GND), U1.23 (GND), U1.35 (GND), U1.43 (GND), U1.45 (GND), Y1.2, Y1.4
LED1: R81.2, U1.12 (PB7)
unnamed: D1.2 (A), MX1.2 (ROW)
unnamed: D2.2 (A), MX2.2 (ROW)
unnamed: D3.2 (A), MX3.2 (ROW)
unnamed: D4.2 (A), MX4.2 (ROW)
unnamed: D5.2 (A), MX5.2 (ROW)
unnamed: D6.2 (A), MX6.2 (ROW)
unnamed: D7.2 (A), MX7.2 (ROW)
unnamed: D8.2 (A), MX8.2 (ROW)
unnamed: D9.2 (A), MX9.2 (ROW)
unnamed: D10.2 (A), MX10.2 (ROW)
unnamed: D11.2 (A), MX11.2 (ROW)
unnamed: D12.2 (A), MX12.2 (ROW)
unnamed: D13.2 (A), MX13.2 (ROW)
unnamed: D14.2 (A), MX14.2 (ROW)
unnamed: D15.2 (A), MX15.2 (ROW)
unnamed: D16.2 (A), MX16.2 (ROW)
unnamed: D17.2 (A), MX17.2 (ROW)
unnamed: D18.2 (A), MX18.2 (ROW)
unnamed: D19.2 (A), MX19.2 (ROW)
unnamed: D20.2 (A), MX20.2 (ROW)
unnamed: D21.2 (A), MX21.2 (ROW)
unnamed: D22.2 (A), MX22.2 (ROW)
unnamed: D23.2 (A), MX23.2 (ROW)
unnamed: D24.2 (A), MX24.2 (ROW)
unnamed: D25.2 (A), MX25.2 (ROW)
unnamed: D26.2 (A), MX26.2 (ROW)
unnamed: D27.2 (A), MX27.2 (ROW)
unnamed: D28.2 (A), MX28.2 (ROW)
unnamed: D29.2 (A), MX29.2 (ROW)
unnamed: D30.2 (A), MX30.2 (ROW)
unnamed: D31.2 (A), MX31.2 (ROW)
unnamed: D32.2 (A), MX32.2 (ROW)
unnamed: D33.2 (A), MX33.2 (ROW)
unnamed: D34.2 (A), MX34.2 (ROW)
unnamed: D35.2 (A), MX35.2 (ROW)
unnamed: D36.2 (A), MX36.2 (ROW)
unnamed: D37.2 (A), MX37.2 (ROW)
unnamed: D38.2 (A), MX38.2 (ROW)
unnamed: D39.2 (A), MX39.2 (ROW)
unnamed: D40.2 (A), MX40.2 (ROW)
unnamed: D41.2 (A), MX41.2 (ROW)
unnamed: D42.2 (A), MX42.2 (ROW)
unnamed: D43.2 (A), MX43.2 (ROW)
unnamed: D44.2 (A), MX44.2 (ROW)
unnamed: D45.2 (A), MX45.2 (ROW)
unnamed: D46.2 (A), MX46.2 (ROW)
unnamed: D47.2 (A), MX47.2 (ROW)
unnamed: D48.2 (A), MX48.2 (ROW)
unnamed: D49.2 (A), MX49.2 (ROW)
unnamed: D50.2 (A), MX50.2 (ROW)
unnamed: D51.2 (A), MX51.2 (ROW)
unnamed: D52.2 (A), MX52.2 (ROW)
unnamed: D53.2 (A), MX53.2 (ROW)
unnamed: D54.2 (A), MX54.2 (ROW)
unnamed: D55.2 (A), MX55.2 (ROW)
unnamed: D56.2 (A), MX56.2 (ROW)
unnamed: D57.2 (A), MX57.2 (ROW)
unnamed: D58.2 (A), MX58.2 (ROW)
unnamed: D59.2 (A), MX59.2 (ROW)
unnamed: D60.2 (A), MX60.2 (ROW)
unnamed: D61.1 (K), R61.2
unnamed: D62.1 (K), R62.2
unnamed: D63.1 (K), R63.2
unnamed: D64.1 (K), R64.2
unnamed: D65.1 (K), R65.2
unnamed: D66.1 (K), R66.2
unnamed: D67.1 (K), R67.2
unnamed: D68.1 (K), R68.2
unnamed: D69.1 (K), R69.2
unnamed: D70.1 (K), R70.2
unnamed: D71.1 (K), R71.2
unnamed: D72.1 (K), R72.2
unnamed: D73.1 (K), R73.2
unnamed: D74.1 (K), R74.2
unnamed: D75.1 (K), R75.2
unnamed: D76.1 (K), R76.2
unnamed: D77.1 (K), R77.2
unnamed: D78.1 (K), R78.2
unnamed: D79.1 (K), R79.2
unnamed: D80.1 (K), R80.2
unnamed: MX1.4 (LEDGND), R1.2
unnamed: MX2.4 (LEDGND), R2.2
unnamed: MX3.4 (LEDGND), R3.2
unnamed: MX4.4 (LEDGND), R4.2
unnamed: MX5.4 (LEDGND), R5.2
unnamed: MX6.4 (LEDGND), R6.2
unnamed: MX7.4 (LEDGND), R7.2
unnamed: MX8.4 (LEDGND), R8.2
unnamed: MX9.4 (LEDGND), R9.2
unnamed: MX10.4 (LEDGND), R10.2
unnamed: MX11.4 (LEDGND), R11.2
unnamed: MX12.4 (LEDGND), R12.2
unnamed: MX13.4 (LEDGND), R13.2
unnamed: MX14.4 (LEDGND), R14.2
unnamed: MX15.4 (LEDGND), R15.2
unnamed: MX16.4 (LEDGND), R16.2
unnamed: MX17.4 (LEDGND), R17.2
unnamed: MX18.4 (LEDGND), R18.2
unnamed: MX19.4 (LEDGND), R19.2
unnamed: MX20.4 (LEDGND), R20.2
unnamed: MX21.4 (LEDGND), R21.2
unnamed: MX22.4 (LEDGND), R22.2
unnamed: MX23.4 (LEDGND), R23.2
unnamed: MX24.4 (LEDGND), R24.2
unnamed: MX25.4 (LEDGND), R25.2
unnamed: MX26.4 (LEDGND), R26.2
unnamed: MX27.4 (LEDGND), R27.2
unnamed: MX28.4 (LEDGND), R28.2
unnamed: MX29.4 (LEDGND), R29.2
unnamed: MX30.4 (LEDGND), R30.2
unnamed: MX31.4 (LEDGND), R31.2
unnamed: MX32.4 (LEDGND), R32.2
unnamed: MX33.4 (LEDGND), R33.2
unnamed: MX34.4 (LEDGND), R34.2
unnamed: MX35.4 (LEDGND), R35.2
unnamed: MX36.4 (LEDGND), R36.2
unnamed: MX37.4 (LEDGND), R37.2
unnamed: MX38.4 (LEDGND), R38.2
unnamed: MX39.4 (LEDGND), R39.2
unnamed: MX40.4 (LEDGND), R40.2
unnamed: MX41.4 (LEDGND), R41.2
unnamed: MX42.4 (LEDGND), R42.2
unnamed: MX43.4 (LEDGND), R43.2
unnamed: MX44.4 (LEDGND), R44.2
unnamed: MX45.4 (LEDGND), R45.2
unnamed: MX46.4 (LEDGND), R46.2
unnamed: MX47.4 (LEDGND), R47.2
unnamed: MX48.4 (LEDGND), R48.2
unnamed: MX49.4 (LEDGND), R49.2
unnamed: MX50.4 (LEDGND), R50.2
unnamed: MX51.4 (LEDGND), R51.2
unnamed: MX52.4 (LEDGND), R52.2
unnamed: MX53.4 (LEDGND), R53.2
unnamed: MX54.4 (LEDGND), R54.2
unnamed: MX55.4 (LEDGND), R55.2
unnamed: MX56.4 (LEDGND), R56.2
unnamed: MX57.4 (LEDGND), R57.2
unnamed: MX58.4 (LEDGND), R58.2
unnamed: MX59.4 (LEDGND), R59.2
unnamed: MX60.4 (LEDGND), R60.2
unnamed: Q1.3 (D), R1.1, R2.1, R3.1, R4.1, R5.1, R6.1, R7.1, R8.1, R9.1, R10.1, R11.1, R12.1, R13.1, R14.1, R15.1, R16.1, R17.1, R18.1, R19.1, R20.1, R21.1, R22.1, R23.1, R24.1, R25.1, R26.1, R27.1, R28.1, R29.1, R30.1, R31.1, R32.1, R33.1, R34.1, R35.1, R36.1, R37.1, R38.1, R39.1, R40.1, R41.1, R42.1, R43.1, R44.1, R45.1, R46.1, R47.1, R48.1, R49.1, R50.1, R51.1, R52.1, R53.1, R54.1, R55.1, R56.1, R57.1, R58.1, R59.1, R60.1, R61.1, R62.1, R63.1, R64.1, R65.1, R66.1, R67.1, R68.1, R69.1, R70.1, R71.1, R72.1, R73.1, R74.1, R75.1, R76.1, R77.1, R78.1, R79.1, R80.1
unnamed: Q1.1 (G), R81.1, R82.1
unnamed: R84.1, U1.4 (D+)
unnamed: R85.1, U1.3 (D-)
unnamed: C3.1, U1.6 (UCAP)
unnamed: C1.1, U1.17 (XTAL1), Y1.1
unnamed: C2.1, U1.16 (XTAL2), Y1.3
unnamed: R86.2, U1.33 (~HWB/PE2)
unnamed: R83.2, SW1.1, U1.13 (~RESET)
ROW0: D1.1 (K), D2.1 (K), D3.1 (K), D4.1 (K), D5.1 (K), D6.1 (K), D7.1 (K), D8.1 (K), D9.1 (K), D10.1 (K), D11.1 (K), D12.1 (K), D13.1 (K), D14.1 (K), D15.1 (K), U1.8 (PB0)
ROW1: D16.1 (K), D17.1 (K), D18.1 (K), D19.1 (K), D20.1 (K), D21.1 (K), D22.1 (K), D23.1 (K), D24.1 (K), D25.1 (K), D26.1 (K), D27.1 (K), D28.1 (K), D29.1 (K), U1.9 (PB1)
ROW2: D30.1 (K), D31.1 (K), D32.1 (K), D33.1 (K), D34.1 (K), D35.1 (K), D36.1 (K), D37.1 (K), D38.1 (K), D39.1 (K), D40.1 (K), D41.1 (K), D42.1 (K), U1.10 (PB2)
ROW3: D43.1 (K), D44.1 (K), D45.1 (K), D46.1 (K), D47.1 (K), D48.1 (K), D49.1 (K), D50.1 (K), D51.1 (K), D52.1 (K), D53.1 (K), D54.1 (K), D55.1 (K), U1.11 (PB3)
ROW4: D56.1 (K), D57.1 (K), D58.1 (K), D59.1 (K), D60.1 (K), U1.37 (PF6)
VCC: F1.1, J1.1

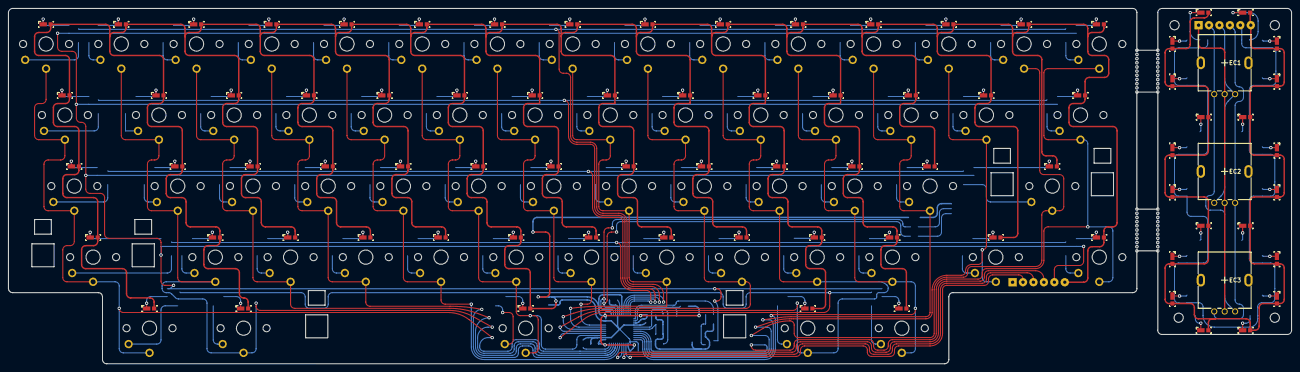
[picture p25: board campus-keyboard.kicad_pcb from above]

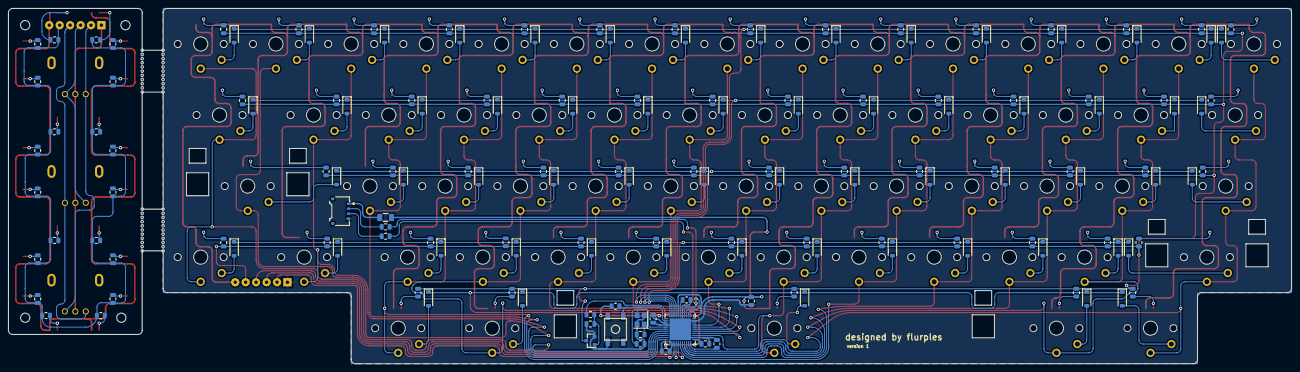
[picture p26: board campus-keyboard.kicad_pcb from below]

Board: 2 copper layers, 307.0 x 85.0 mm, 242 parts (159 on the bottom side), 178 nets.

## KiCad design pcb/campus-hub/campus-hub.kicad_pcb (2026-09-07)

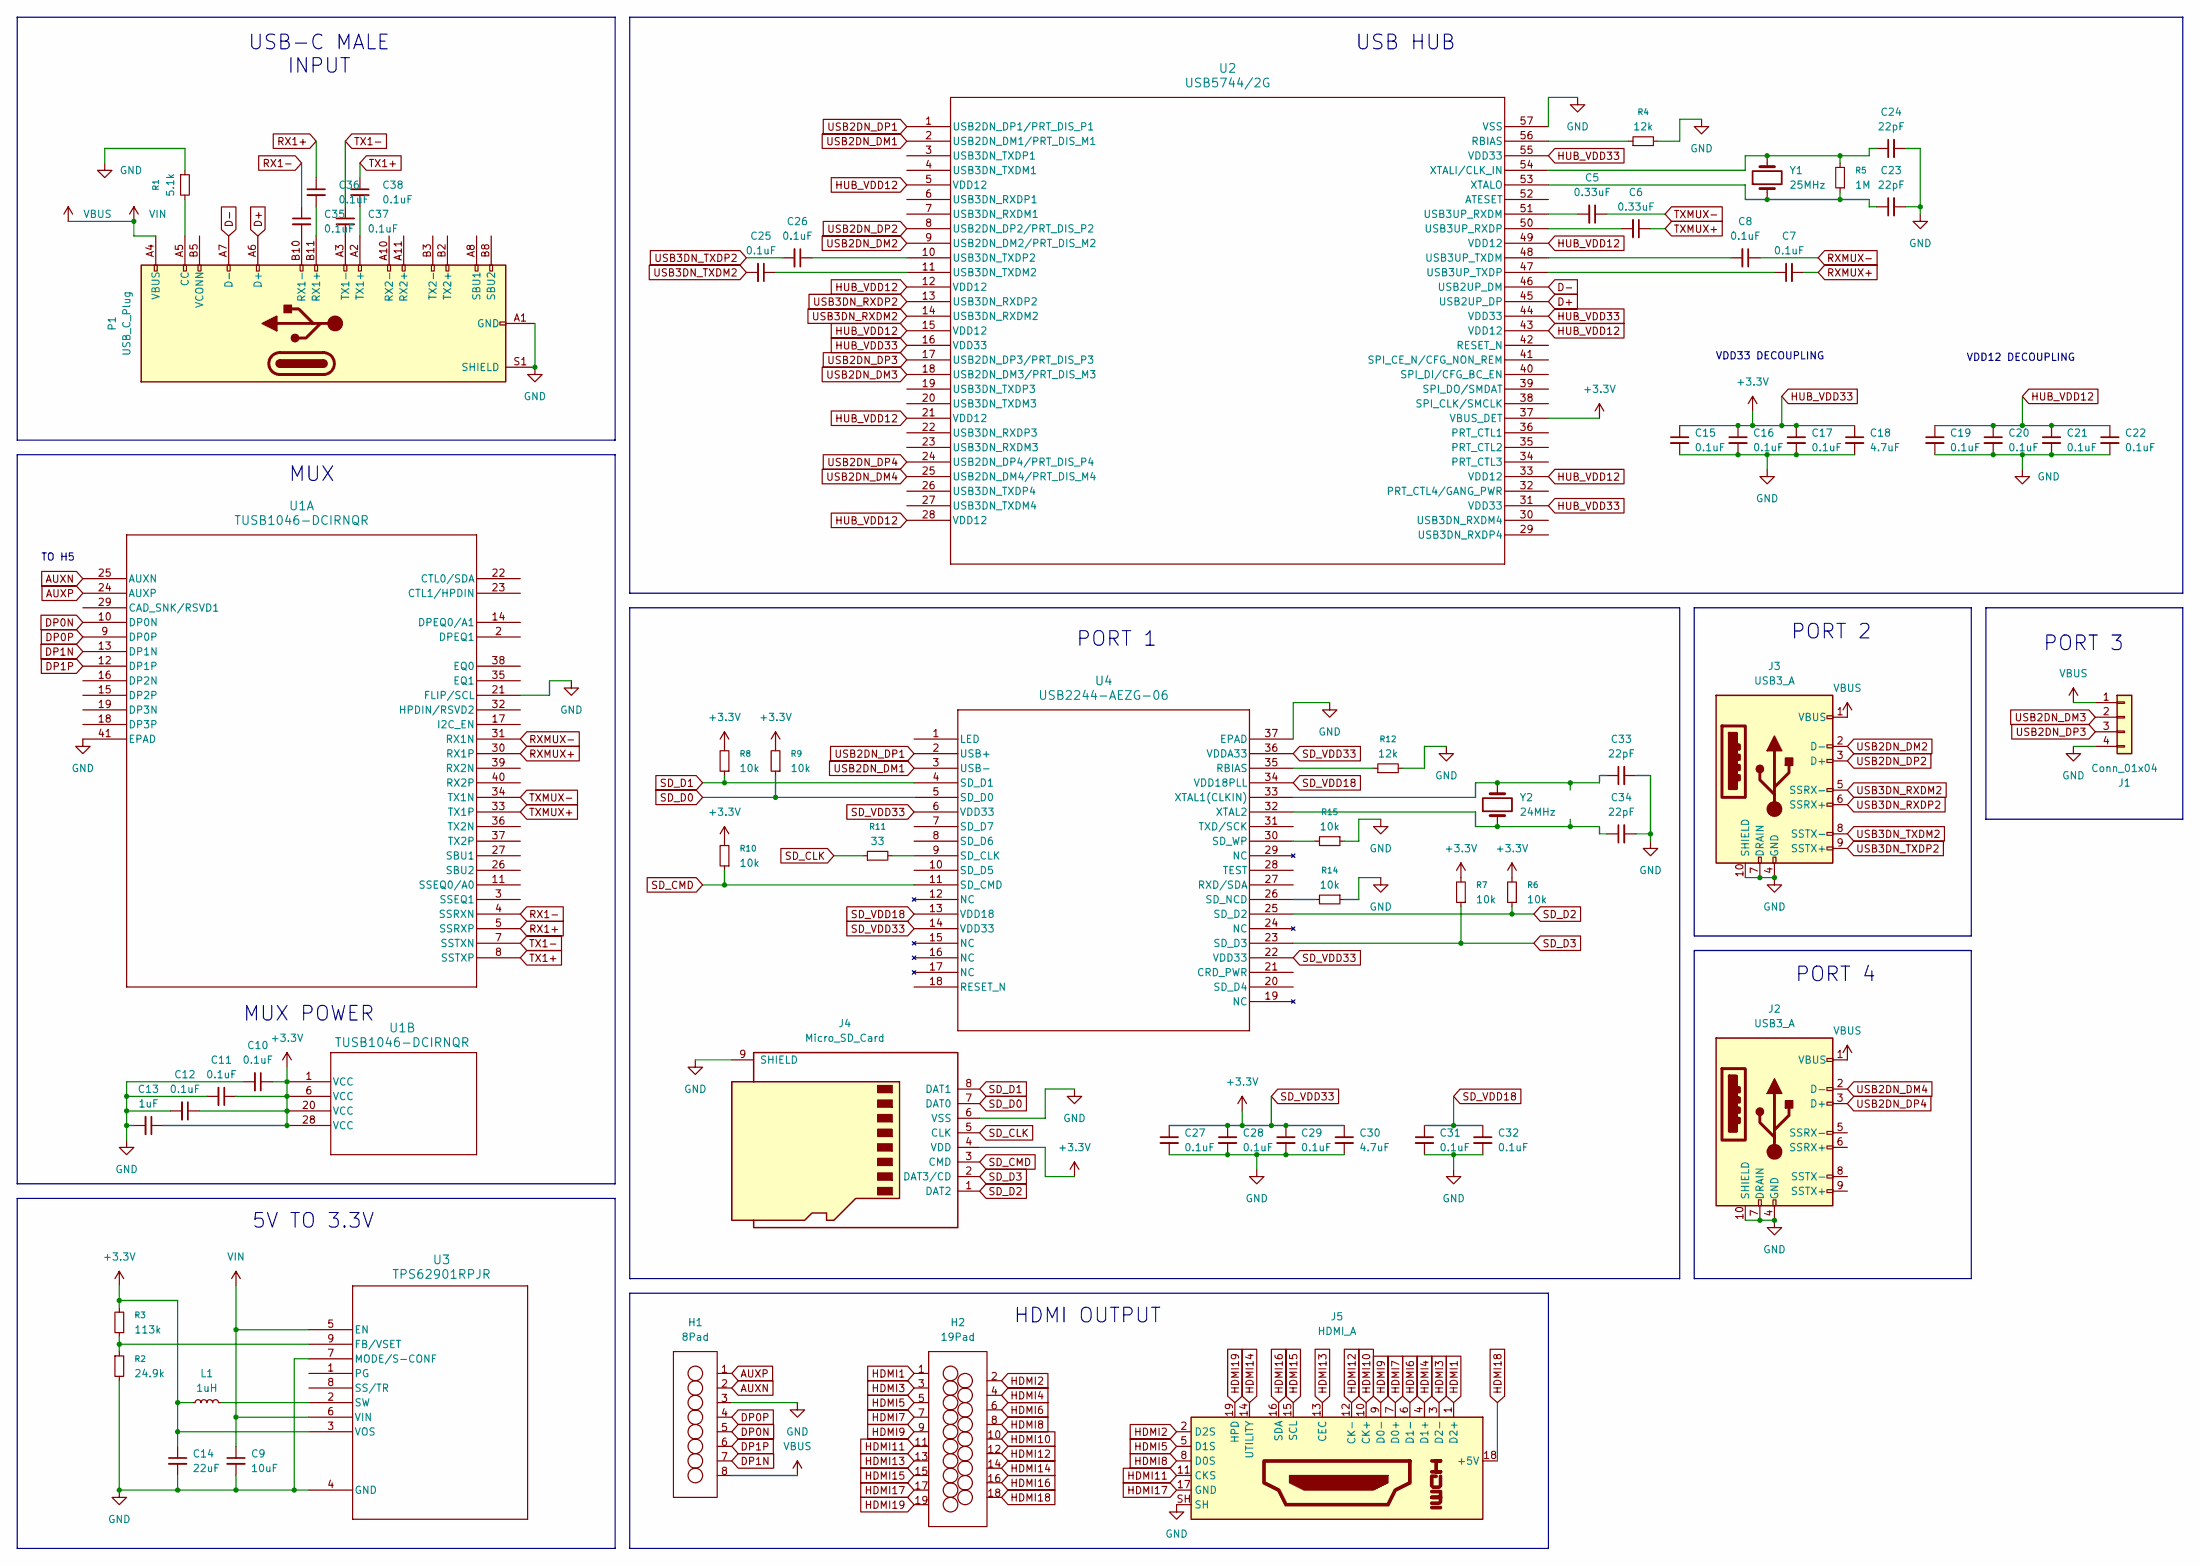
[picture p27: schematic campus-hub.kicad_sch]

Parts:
C5, C6: 0.33uF; C_0805_2012Metric
C7, C8, C10, C11, C12, C15, C16, C17, C19, C20, C21, C22, C25, C26, C27, C28, C29, C31, C32, C35, C36, C37, C38: 0.1uF; C_0805_2012Metric
C9: 10uF; C_0805_2012Metric
C13: 1uF; C_0805_2012Metric
C14: 22uF; C_0805_2012Metric
C18, C30: 4.7uF; C_0805_2012Metric
C23, C24, C33, C34: 22pF; C_0805_2012Metric
H1: 8Pad
H2: 19Pad
J1: Conn_01x04; Molex_Pico-EZmate_78171-0004_1x04-1MP_P1.20mm_Vertical
J2, J3: USB3_A; 692121230100
J4: Micro_SD_Card; 104031-0811_MOL
J5: HDMI_A; SAMESKY_HD07-19-RVS-MSMT-TR
L1: 1uH; L_1008_2520Metric
P1: USB_C_Plug; MOLEX_1054440001
R1: 5.1k; R_0805_2012Metric
R2: 24.9k; R_0805_2012Metric
R3: 113k; R_0805_2012Metric
R4, R12: 12k; R_0805_2012Metric
R5: 1M; R_0805_2012Metric
R6, R7, R8, R9, R10, R14, R15: 10k; R_0805_2012Metric
R11: 33; R_0805_2012Metric
U1: TUSB1046-DCIRNQR; RNQ40_TEX
U2: USB5744/2G; VQFN56_2G_MCH
U3: TPS62901RPJR; QFN_902RPJR_TEX
U4: USB2244-AEZG-06; QFN36_6X6MC_MCH
Y1: 25MHz; Crystal_SMD_3225-4Pin_3.2x2.5mm
Y2: 24MHz; Crystal_SMD_3225-4Pin_3.2x2.5mm

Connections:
AUXN: H1.2, U1.25 (AUXN)
AUXP: H1.1, U1.24 (AUXP)
D+: P1.A6 (D+), U2.45 (USB2UP_DP)
D-: P1.A7 (D-), U2.46 (USB2UP_DM)
DP0N: H1.5, U1.10 (DP0N)
DP0P: H1.4, U1.9 (DP0P)
DP1N: H1.7, U1.13 (DP1N)
DP1P: H1.6, U1.12 (DP1P)
GND: C9.2, C10.2, C11.2, C12.2, C13.2, C14.2, C15.2, C16.2, C17.2, C18.2, C19.2, C20.2, C21.2, C22.2, C23.2, C24.2, C27.2, C28.2, C29.2, C30.2, C31.2, C32.2, C33.2, C34.2, H1.3, J1.4, J2.4 (GND), J2.7 (DRAIN), J2.10 (SHIELD), J3.4 (GND), J3.7 (DRAIN), J3.10 (SHIELD), J4.6 (VSS), J4.9 (SHIELD), J4.11, J4.12, J4.13, J4.14, J5.SH, P1.A1 (GND), P1.A12 (GND), P1.B1 (GND), P1.B12 (GND), P1.S1 (SHIELD), P1.SH1, R1.1, R2.2, R4.2, R12.2, R14.1, R15.1, U1.21 (FLIP/SCL), U1.41 (EPAD), U2.57 (VSS), U3.4 (GND), U3.7 (MODE/S-CONF), U4.37 (EPAD), Y1.2, Y1.4, Y2.2, Y2.4
HDMI1: H2.1, J5.1 (D2+)
HDMI2: H2.2, J5.2 (D2S)
HDMI3: H2.3, J5.3 (D2-)
HDMI4: H2.4, J5.4 (D1+)
HDMI5: H2.5, J5.5 (D1S)
HDMI6: H2.6, J5.6 (D1-)
HDMI7: H2.7, J5.7 (D0+)
HDMI8: H2.8, J5.8 (D0S)
HDMI9: H2.9, J5.9 (D0-)
HDMI10: H2.10, J5.10 (CK+)
HDMI11: H2.11, J5.11 (CKS)
HDMI12: H2.12, J5.12 (CK-)
HDMI13: H2.13, J5.13 (CEC)
HDMI14: H2.14, J5.14 (UTILITY)
HDMI15: H2.15, J5.15 (SCL)
HDMI16: H2.16, J5.16 (SDA)
HDMI17: H2.17, J5.17 (GND)
HDMI18: H2.18, J5.18 (+5V)
HDMI19: H2.19, J5.19 (HPD)
HUB_VDD12: C19.1, C20.1, C21.1, C22.1, U2.5 (VDD12), U2.12 (VDD12), U2.15 (VDD12), U2.21 (VDD12), U2.28 (VDD12), U2.33 (VDD12), U2.43 (VDD12), U2.49 (VDD12)
HUB_VDD33: C10.1, C11.1, C12.1, C13.1, C14.1, C15.1, C16.1, C17.1, C18.1, C27.1, C28.1, C29.1, C30.1, J4.4 (VDD), L1.1, R3.2, R6.2, R7.2, R8.2, R9.2, R10.2, U1.1 (VCC), U1.6 (VCC), U1.20 (VCC), U1.28 (VCC), U2.16 (VDD33), U2.31 (VDD33), U2.37 (VBUS_DET), U2.44 (VDD33), U2.55 (VDD33), U3.3 (VOS), U4.6 (VDD33), U4.14 (VDD33), U4.22 (VDD33), U4.36 (VDDA33)
unnamed: P1.A5 (CC), R1.2
unnamed: C36.2, P1.B11 (RX1+)
unnamed: C35.2, P1.B10 (RX1-)
unnamed: C38.2, P1.A2 (TX1+)
unnamed: C37.2, P1.A3 (TX1-)
unnamed: R4.1, U2.56 (RBIAS)
unnamed: C25.1, U2.11 (USB3DN_TXDM2)
unnamed: C26.1, U2.10 (USB3DN_TXDP2)
unnamed: C5.2, U2.51 (USB3UP_RXDM)
unnamed: C6.2, U2.50 (USB3UP_RXDP)
unnamed: C8.2, U2.48 (USB3UP_TXDM)
unnamed: C7.1, U2.47 (USB3UP_TXDP)
unnamed: C24.1, R5.2, U2.54 (XTALI/CLK_IN), Y1.3
unnamed: C23.1, R5.1, U2.53 (XTALO), Y1.1
unnamed: R2.1, R3.1, U3.9 (FB/VSET)
unnamed: L1.2, U3.2 (SW)
unnamed: R12.1, U4.35 (RBIAS)
unnamed: R11.2, U4.9 (SD_CLK)
unnamed: R14.2, U4.26 (SD_NCD)
unnamed: R15.2, U4.30 (SD_WP)
unnamed: C33.1, U4.33 (XTAL1(CLKIN)), Y2.3
unnamed: C34.1, U4.32 (XTAL2), Y2.1
RX1+: C36.1, U1.5 (SSRXP)
RX1-: C35.1, U1.4 (SSRXN)
RXMUX+: C7.2, U1.30 (RX1P)
RXMUX-: C8.1, U1.31 (RX1N)
SD_CLK: J4.5 (CLK), R11.1
SD_CMD: J4.3 (CMD), R10.1, U4.11 (SD_CMD)
SD_D0: J4.7 (DAT0), R9.1, U4.5 (SD_D0)
SD_D1: J4.8 (DAT1), R8.1, U4.4 (SD_D1)
SD_D2: J4.1 (DAT2), R6.1, U4.25 (SD_D2)
SD_D3: J4.2 (DAT3/CD), R7.1, U4.23 (SD_D3)
SD_VDD18: C31.1, C32.1, U4.13 (VDD18), U4.34 (VDD18PLL)
TX1+: C38.1, U1.8 (SSTXP)
TX1-: C37.1, U1.7 (SSTXN)
TXMUX+: C6.1, U1.33 (TX1P)
TXMUX-: C5.1, U1.34 (TX1N)
USB2DN_DM1: U2.2 (USB2DN_DM1/PRT_DIS_M1), U4.3 (USB-)
USB2DN_DM2: J3.2 (D-), U2.9 (USB2DN_DM2/PRT_DIS_M2)
USB2DN_DM3: J1.2, U2.18 (USB2DN_DM3/PRT_DIS_M3)
USB2DN_DM4: J2.2 (D-), U2.25 (USB2DN_DM4/PRT_DIS_M4)
USB2DN_DP1: U2.1 (USB2DN_DP1/PRT_DIS_P1), U4.2 (USB+)
USB2DN_DP2: J3.3 (D+), U2.8 (USB2DN_DP2/PRT_DIS_P2)
USB2DN_DP3: J1.3, U2.17 (USB2DN_DP3/PRT_DIS_P3)
USB2DN_DP4: J2.3 (D+), U2.24 (USB2DN_DP4/PRT_DIS_P4)
USB3DN_RXDM2: J3.5 (SSRX-), U2.14 (USB3DN_RXDM2)
USB3DN_RXDP2: J3.6 (SSRX+), U2.13 (USB3DN_RXDP2)
USB3DN_TXDM2: C25.2, J3.8 (SSTX-)
USB3DN_TXDP2: C26.2, J3.9 (SSTX+)
VBUS: C9.1, H1.8, J1.1, J2.1 (VBUS), J3.1 (VBUS), P1.A4 (VBUS), P1.A9 (VBUS), P1.B4 (VBUS), P1.B9 (VBUS), U3.5 (EN), U3.6 (VIN)

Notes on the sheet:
PORT 2
VDD12 DECOUPLING
USB HUB
HDMI OUTPUT
PORT 4
MUX
MUX POWER
USB-C MALE INPUT
5V TO 3.3V
TO H5
PORT 1
PORT 3
VDD33 DECOUPLING

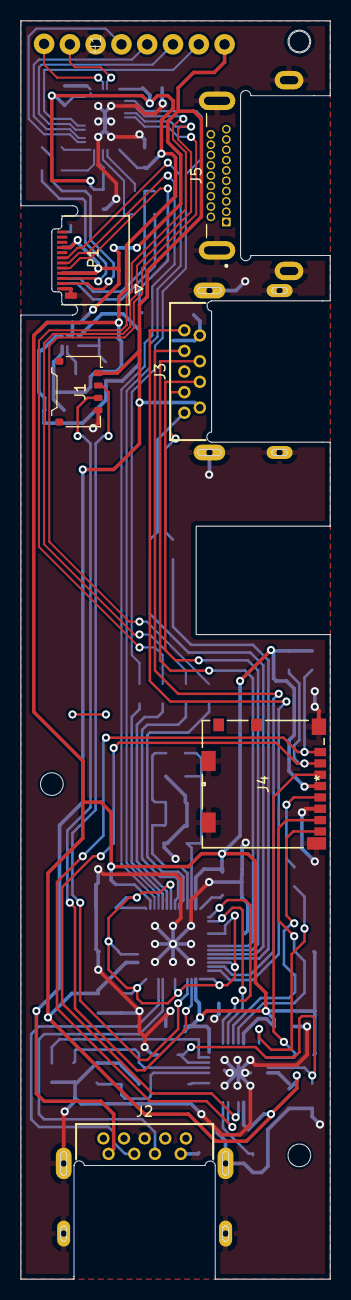
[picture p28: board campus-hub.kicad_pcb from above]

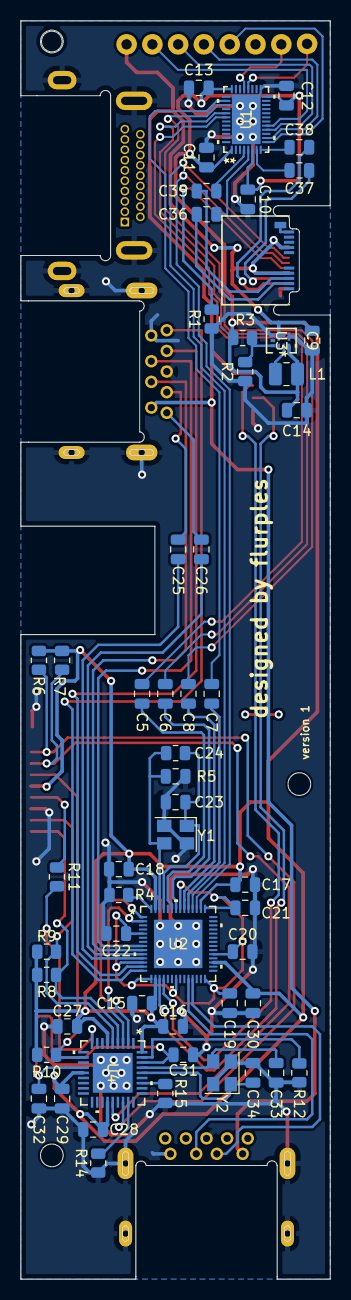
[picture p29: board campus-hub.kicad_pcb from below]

Board: 2 copper layers, 30.0 x 122.0 mm, 62 parts (55 on the bottom side), 61 nets.

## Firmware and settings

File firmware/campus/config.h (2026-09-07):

#pragma once

#include "config_common.h"

/* USB Device descriptor parameter */
#define VENDOR_ID       0x4650 // [f]lur[p]les
#define PRODUCT_ID      0x6780 // [C]am[P]us
#define DEVICE_VER      0x0001
#define PRODUCT         Campus

/* key matrix size */
#define MATRIX_ROWS 5
#define MATRIX_COLS 15

#define MATRIX_ROW_PINS { B0, B1, B2, B3, F6 }
#define MATRIX_COL_PINS { C7, C6, B6, B5, B4, F7, F0, F1, F4, F5, D5, D3, D2, D1, D0 }
#define DIODE_DIRECTION COL2ROW

#define ENCODERS_PAD_A { D4, D6, D7 }
#define ENCODERS_PAD_B { D6, D7, D4 }
#define ENCODER_RESOLUTION 4

#define BACKLIGHT_PIN B7
#define BACKLIGHT_DEFAULT_ON
#define BACKLIGHT_LEVELS 12
#define BACKLIGHT_DEFAULT_LEVEL 12

#define DYNAMIC_KEYMAP_LAYER_COUNT 4

/* Set 0 if debouncing is not needed */
#define DEBOUNCE 5

/* define if matrix has ghost */
//#define MATRIX_HAS_GHOST

/* Mechanical locking support. Use KC_LCAP, KC_LNUM or KC_LSCR instead in keymap */
#define LOCKING_SUPPORT_ENABLE
/* Locking resynchronize hack */
#define LOCKING_RESYNC_ENABLE

/* disable action features */
//#define NO_ACTION_LAYER
//#define NO_ACTION_TAPPING
//#define NO_ACTION_ONESHOT

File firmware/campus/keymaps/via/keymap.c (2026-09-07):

/* made with <3 by flurples */

#include QMK_KEYBOARD_H

bool encoder_update_user(uint8_t index, bool clockwise) {
  if (index == 0) { /* First encoder */
    if (clockwise) {
      tap_code(KC_VOLU);
    } else {
      tap_code(KC_VOLD);
    }
  } else if (index == 1) { /* Second encoder */
    if (clockwise) {
      tap_code(KC_BRIU);
    } else {
      tap_code(KC_BRID);
    }
} else if (index == 2) { /* Third encoder */
    if (clockwise) {
      void backlight_increase(void) ;
    } else {
      void backlight_decrease(void) ;
    }
  }
  return true;
}

const uint16_t PROGMEM keymaps[][MATRIX_ROWS][MATRIX_COLS] = {

// Default layer
[0] = LAYOUT_all(
	BL_INC,  KC_1,    KC_2,    KC_3,    KC_4,    KC_5,    KC_6,    KC_7,    KC_8,    KC_9,    KC_0,    KC_MINS, KC_EQL,  KC_BSLS, KC_GRV, 
	KC_TAB,  KC_Q,    KC_W,    KC_E,    KC_R,    KC_T,    KC_Y,    KC_U,    KC_I,    KC_O,    KC_P,    KC_LBRC, KC_RBRC,          KC_BSPC, 
	KC_LCTL, KC_A,    KC_S,    KC_D,    KC_F,    KC_G,    KC_H,    KC_J,    KC_K,    KC_L,    KC_SCLN, KC_QUOT,          KC_ENT, 
	KC_LSFT, KC_Z,    KC_X,    KC_C,    KC_V,    KC_B,    KC_N,    KC_M,    KC_COMM, KC_DOT,  KC_SLSH,          KC_RSFT,          MO(1), 
	KC_LGUI, KC_LALT,                            KC_SPC,                             KC_RALT, KC_RGUI), 

// Fn1 Layer
[1] = LAYOUT_all(
	KC_TRNS, KC_F1,   KC_F2,   KC_F3,   KC_F4,   KC_F5,   KC_F6,   KC_F7,   KC_F8,   KC_F9,   KC_F10,  KC_F11,  KC_F12,  KC_TRNS, KC_F13, 
	KC_TRNS, KC_TRNS, KC_TRNS, KC_TRNS, KC_TRNS, KC_TRNS, KC_TRNS, KC_TRNS, KC_TRNS, KC_TRNS, KC_TRNS, KC_UP,   KC_TRNS,          KC_DEL, 
	KC_CAPS, KC_TRNS, KC_TRNS, KC_TRNS, KC_TRNS, KC_TRNS, KC_TRNS, KC_TRNS, KC_TRNS, KC_TRNS, KC_LEFT, KC_RGHT,          KC_TRNS, 
	KC_TRNS, KC_TRNS, KC_TRNS, KC_TRNS, KC_TRNS, KC_TRNS, KC_TRNS, KC_TRNS, KC_TRNS, KC_TRNS, KC_DOWN,          MO(2),            KC_TRNS, 
	KC_TRNS, KC_TRNS,                            KC_TRNS,                            KC_TRNS, KC_TRNS),

// Fn2 Layer
[2] = LAYOUT_all(
	KC_TRNS, KC_TRNS, KC_TRNS, KC_TRNS, KC_TRNS, KC_TRNS, KC_TRNS, KC_TRNS, KC_TRNS, KC_TRNS, KC_TRNS, KC_TRNS, KC_TRNS, KC_TRNS, KC_TRNS, 
	KC_TRNS, KC_TRNS, KC_TRNS, KC_TRNS, KC_TRNS, KC_TRNS, KC_TRNS, KC_TRNS, KC_TRNS, KC_TRNS, KC_TRNS, KC_VOLU, KC_TRNS,          KC_TRNS, 
	KC_TRNS, KC_TRNS, KC_TRNS, KC_TRNS, KC_TRNS, KC_TRNS, KC_TRNS, KC_TRNS, KC_TRNS, KC_TRNS, KC_MPRV, KC_MNXT,          KC_TRNS, 
	KC_TRNS, KC_TRNS, KC_TRNS, KC_TRNS, KC_TRNS, KC_TRNS, KC_TRNS, KC_TRNS, KC_TRNS, KC_TRNS, KC_VOLD,          KC_TRNS,          KC_TRNS, 
	KC_TRNS, KC_TRNS,                            KC_MPLY,                            KC_TRNS, KC_TRNS),

// Fn3 Layer
[3] = LAYOUT_all(
	KC_TRNS, KC_TRNS, KC_TRNS, KC_TRNS, KC_TRNS, KC_TRNS, KC_TRNS, KC_TRNS, KC_TRNS, KC_TRNS, KC_TRNS, KC_TRNS, KC_TRNS, KC_TRNS, KC_TRNS, 
	KC_TRNS, KC_TRNS, KC_TRNS, KC_TRNS, KC_TRNS, KC_TRNS, KC_TRNS, KC_TRNS, KC_TRNS, KC_TRNS, KC_TRNS, KC_TRNS, KC_TRNS,          KC_TRNS, 
	KC_TRNS, KC_TRNS, KC_TRNS, KC_TRNS, KC_TRNS, KC_TRNS, KC_TRNS, KC_TRNS, KC_TRNS, KC_TRNS, KC_TRNS, KC_TRNS,          KC_TRNS, 
	KC_TRNS, KC_TRNS, KC_TRNS, KC_TRNS, KC_TRNS, KC_TRNS, KC_TRNS, KC_TRNS, KC_TRNS, KC_TRNS, KC_TRNS,          KC_TRNS,          KC_TRNS, 
	KC_TRNS, KC_TRNS,                            KC_TRNS,                            KC_TRNS, KC_TRNS),

};

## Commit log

2026-09-06 add 3d files
    [bezel.step, bottom-bracket-L.step, bottom-bracket-M.step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]
2026-09-07 add pcb files
    [campus-keyboard-bom.csv, campus-keyboard.kicad_pcb, campus-keyboard.kicad_sch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]
